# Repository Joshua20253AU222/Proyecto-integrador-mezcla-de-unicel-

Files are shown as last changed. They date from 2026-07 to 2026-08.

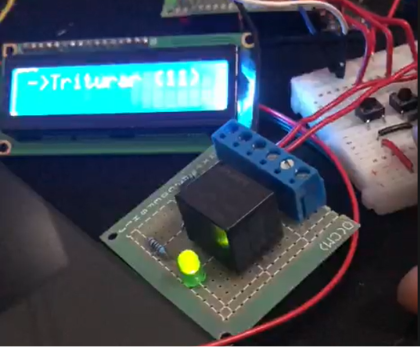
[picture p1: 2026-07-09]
Imágenes/Relevador prueba.png

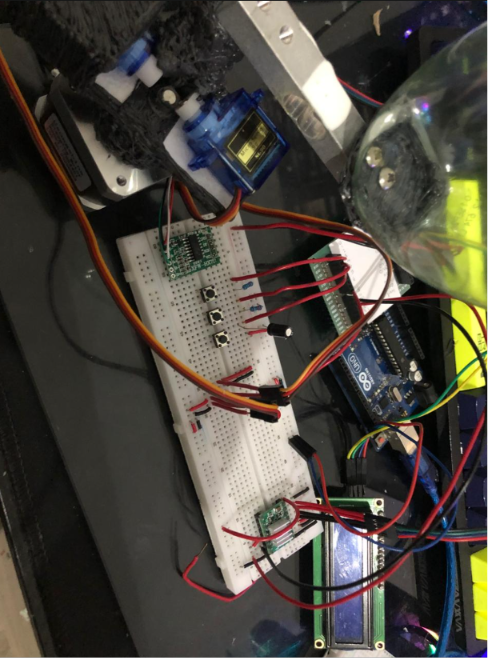
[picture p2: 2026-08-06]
Imágenes/Circuito de control del brazo recolector.png

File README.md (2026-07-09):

# Proyecto-integrador-mezcla-de-unicel-
Nombre del proyecyo:
<h3>Diseño y desarrollo de sistema semi automático de mezcla para la elaboración de bloques ecológicos de cemento y unicel.</h3>

El proyecto se enfoca en hacer una mezcla basada principalmente en unicel para la elaboración de placas o blocks con unicel, haciendo que estas sean ligeras y termoasilantes. Su uso varía desde aplicaciones en fachadas para disminución de temperaturas en inmuebles a una opción de mezcla para uso decorativo, como pisos para jardineras, etc.

El proyecto se divide en 3 sistemas clave:

<ol>
<li type="circle">Sistema de triturado:</li>
<i>Se encarga de triturar el unicel y alamacenarlo en una tolva para su posterior uso.</i>
<br><br>
<li type="circle">Sistema de mesurado:</li>
<i>Se encarga de cuantificar y dosificar los materiales necesarios para hacer la mezcla.</i>
<br><br>
<li type="circle">Sistema de Mezclado:</li>
<i>Se encarga de mezclar los materiales para obtener la mezcla final.</i>

</ol>

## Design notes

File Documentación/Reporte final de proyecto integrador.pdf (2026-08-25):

## UNIVERSIDAD TECNOLÓGICA EMILIANO ZAPATA DEL ESTADO DE

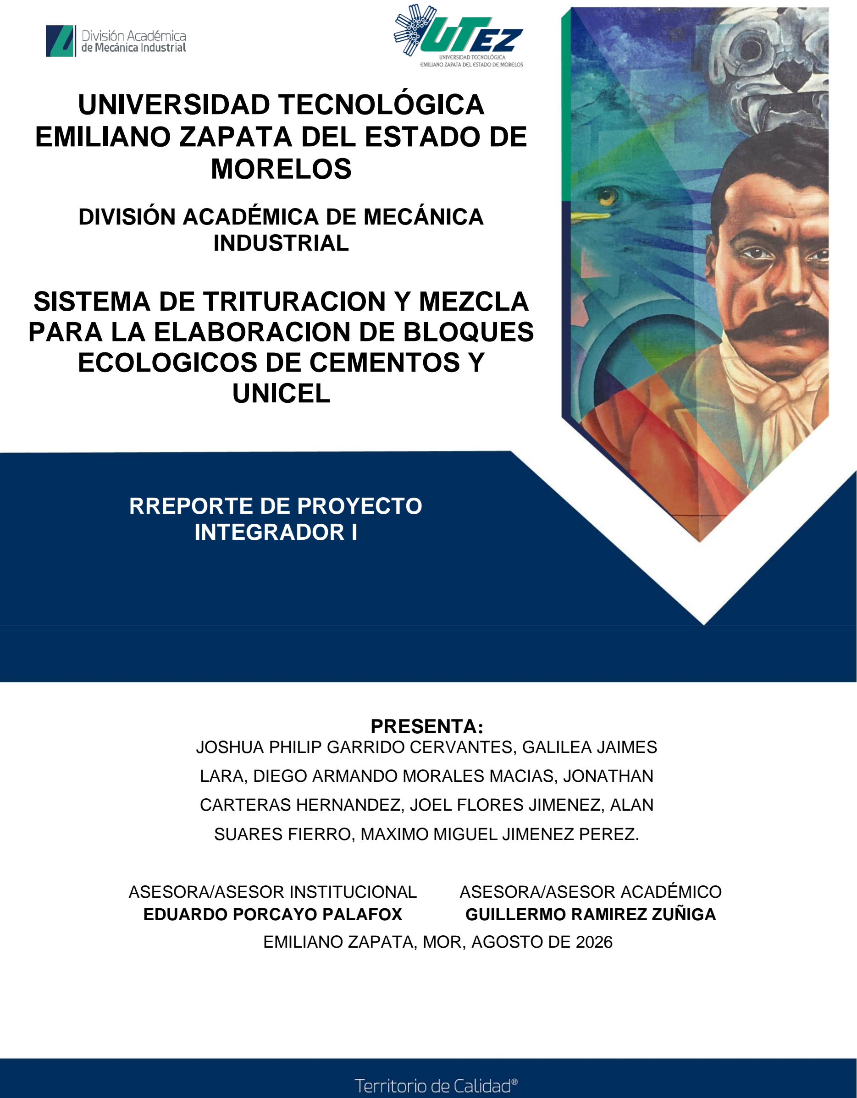
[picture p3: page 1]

PRESENTA:
JOSHUA PHILIP GARRIDO CERVANTES, GALILEA JAIMES

LARA, DIEGO ARMANDO MORALES MACIAS, JONATHAN

CARTERAS HERNANDEZ, JOEL FLORES JIMENEZ, ALAN

SUARES FIERRO, MAXIMO MIGUEL JIMENEZ PEREZ.

ASESORA/ASESOR INSTITUCIONAL | ASESORA/ASESOR ACADÉMICO
EDUARDO PORCAYO PALAFOX | GUILLERMO RAMIREZ ZUÑIGA

## RREPORTE DE PROYECTO INTEGRADOR I

EMILIANO ZAPATA, MOR, AGOSTO DE 2026

## MORELOS

## DIVISIÓN ACADÉMICA DE MECÁNICA INDUSTRIAL

## SISTEMA DE TRITURACION Y MEZCLA PARA LA ELABORACION DE BLOQUES ECOLOGICOS DE CEMENTOS Y UNICEL

## CONTENIDO

Índice de figuras

Índice de tablas

Agradecimientos

Resumen

Summary

REFERENCIAS

## ÍNDICE DE FIGURAS

Figura 5.1 Bosquejos finales del ensamblado total de la mezcladora y la trituradora 16

Figura 12.1 Estructura principal realizada con el módulo mezclador en la parte inferior

Figura 14.1 Mezcla de unicel, arena y agua para la formulación del bloque hexagonal

Figura 15.1 Bloque realizado a partir de la trituración de unicel y la mezcla con

Figura 16.1 Sistemas de almacenaje de arena para después integrarlo con el

## ÍNDICE DE TABLAS

## AGRADECIMIENTOS

Agradezco a:

- A mis profesores, por compartir sus conocimientos, guiarnos pacientemente a

lo largo de este proyecto integrador y brindarnos el apoyo técnico necesario

para llevar a cabo la construcción de este prototipo.

- A la Universidad Tecnológica Emiliano Zapata del Estado de Morelos (UTEZ),

por facilitarnos las instalaciones, laboratorios y herramientas indispensables

para el desarrollo, manufactura y pruebas de este sistema.

- A mis compañeros de equipo, por su dedicación, esfuerzo compartido y trabajo

constante durante las doce semanas de desarrollo para hacer realidad este

proyecto.

## RESUMEN

En la actualidad, las instituciones de educación superior enfrentan el reto de

implementar soluciones tecnológicas que respondan de manera efectiva a los

problemas de contaminación y gestión de residuos que afectan al país. Por ello,

a través de la investigación aplicada y el desarrollo de proyectos integradores

sustentables, las universidades reafirman su responsabilidad social y ambiental,

buscando transferir tecnologías eficientes que beneficien a los sectores

comunitario, productivo.

En este documento se encuentra el desarrollo de un proyecto realizado en el

ámbito de la Universidad Tecnológica Emiliano Zapata del Estado de Morelos,

a fin de determinar la viabilidad y diseño de un sistema semiautomático de flujo

continuo para el reciclaje de poliestireno expandido (unicel). El objetivo es que

la institución cuente con una alternativa tecnológica eficiente para transformar

un residuo de alto impacto ecológico en un material constructivo termoaislante

de valor agregado.

La investigación incluye el planteamiento de la problemática derivada del uso

excesivo y la difícil degradación del unicel, así como los diferentes elementos

que describen la forma en que se diseñó el sistema y sus alcances. De esta

manera, se tiene claramente definido el objetivo a alcanzar y los medios técnicos

que se utilizarán para dicho propósito.

Todo proyecto de integración tecnológica requiere de un marco teórico base que

fundamente la investigación realizada, de tal forma que le dé la veracidad y

objetividades requeridas. Por lo cual, se exponen de forma explícita los

fundamentos de la dosificación de materiales (cemento, cal, arena y unicel), los

principios del aislamiento térmico y el ahorro energético en inmuebles.

La determinación de la aplicabilidad del sistema, objetivo principal de este

trabajo, se desarrolla de forma clara, detallando el proceso de automatización y

control a cargo del operador. A través de diferentes técnicas de diseño, se

obtiene un trabajo significativo que culmina con la creación de un manual de

operación para la fabricación de paneles y bloques ligeros, lo que da pie a una

solución de utilidad y diagnóstico para la gestión ambiental y constructiva dentro

y fuera de la universidad.

## SUMMARY

Currently, higher education institutions face the challenge of implementing

technological solutions that effectively address the pollution and waste

management problems affecting the country. Therefore, through applied

research and the development of sustainable, integrated projects, universities

reaffirm their social and environmental responsibility, seeking to transfer efficient

technologies that benefit the community and productive sectors.

This document presents the development of a project carried out at the Emiliano

Zapata Technological University in the State of Morelos, aimed at determining

the feasibility and design of a semi-automatic, continuous-flow system for

recycling expanded polystyrene (Styrofoam). The objective is for the institution

to have an efficient technological alternative for transforming a high-impact

ecological waste product into a value-added, thermally insulating building

material.

The research includes an analysis of the problems arising from the excessive

use and slow degradation of Styrofoam, as well as the various elements that

describe how the system was designed and its scope. In this way, the objective

to be achieved and the technical means to be used for this purpose are clearly

defined.

Every technological integration project requires a basic theoretical framework to

support the research conducted, thus providing the necessary veracity and

objectivity. Therefore, the fundamentals of material dosage (cement, lime, sand,

and polystyrene), the principles of thermal insulation, and energy savings in

buildings are explicitly presented.

4

The determination of the system's applicability, the main objective of this work,

is clearly developed, detailing the automation and control process managed by

the operator. Through different design techniques, significant work is obtained,

culminating in the creation of an operating manual for the manufacture of

lightweight panels and blocks. This provides a useful and diagnostic solution for

environmental and construction management both within and outside the

university.

## CAPÍTULO 1.DESCRIPCIÓN DEL PROYECTO

### 1.1 Planteamiento del problema

El unicel, por años ha sido un material difícil de manejar en el área de reciclaje.

Su uso es principalmente desechable y su huella ecológica es muy alta, debido

a que:

- No es biodegradable: tarda más de 500 años en degradarse.
- Amenaza a la fauna: Los animales marinos y aves lo confunden con

alimento.

- Genera micro plásticos: Se desmenuza fácilmente, contaminando suelas,

ríos y océanos.

En la Universidad Tecnológica Emiliano Zapata del Estado de Morelos, a pesar

de que está prohibido el ingreso y uso del unicel, por diversos factores sigue

ingresando este material a la universidad. Por lo que, buscar qué hacer con este

material puede ser un punto de interés para la universidad.

Esta mezcla, al usarse en estructuras o edificios, permite un aislamiento de

temperatura considerable. Y en caso de inmuebles que usen aires

acondicionados, implica un ahorro de energía, al contener y mantener una

temperatura agradable, evitando cargos energéticos excesivos.

### 1.2 Objetivos

### 1.2.1 General

Buscar la forma de reciclar el unicel en el plantel, al mismo tiempo de darle un

uso que no implique que el material se vuelva en otro producto desechable.

Crear un sistema que utilice el unicel para que, en conjunto de otros materiales

(como cemento, cal y/o arena), formar una mezcla de unicel y estos materiales para hacer placas/blocks termo aislantes y de peso ligero para uso interior y

exterior.

### 1.2.2 Específicos

Crear un sistema que pueda hacer la mezcla de forma semi automática de flujo

continuo, siendo que exista un operador que programe la máquina primero,

tomando en cuenta, se generan los siguientes puntos:

- Los materiales se colocan en la máquina, esta misma los dosifica.
- La mezcla no es específica, el operador es el encargado técnico de

programar el sistema para que la máquina genere la mezcla con diferentes

propiedades según las necesidades y área de aplicación.

Además, se busca generar un pequeño manual de operación, el cuál

especificará dos principales tipos de mezcla: Para paneles y para blocks.

Ambos teniendo cantidades de material diferentes, siendo esta la idea principal.

### 1.3 Justificación

Hacer este sistema da la oportunidad a empresas, centros de acopio y escuelas

medianas o grandes, de reciclar unicel de forma beneficiosa.

Así como ayudar a generar material de construcción que sea más viable de

transportar que el mismo unicel, ya que, al transportar unicel, se transporta más

aire que material (un 98% de aire aproximadamente).

De la misma forma se puede usar de forma casera este sistema, trayendo

beneficios a muchas personas y ampliando el área de oportunidad del proyecto.

En general, es una solución a los residuos excesivos del unicel en un enfoque

que beneficia al bienestar de las personas quienes usen esta tecnología en

aulas, oficinas y hogares en tanto al manejo de temperaturas.

### 1.4 Alcances

Alcances:

- Las propiedades de los materiales y su calidad son responsabilidad del

operador.

- La máquina solo manejará el uso y mesurado de 3 materiales por mezcla.
- Se harán dos principales moldes, pero la mezcla puede usarse para un

molde personalizado.

- El uso de unicel debe de pasar por un proceso de limpieza en caso de

contener residuos de alimentos o grasas.

- Se especificará en el manual una forma en la que se puedan colocar las

placas aislantes fuera de un edificio, casa o inmueble.

### 1.5 Datos generales de la empresa

Nombre

Universidad Tecnología Emiliano Zapata Del Estado De Morelos

Logotipo

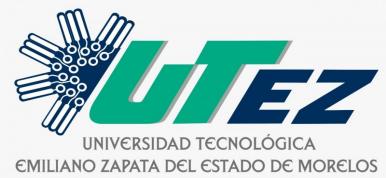
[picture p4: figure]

Figura 1.1 Logotipo de la empresa

Dirección

Avenida Universidad Tecnológica 1 Palo Escrito, 62765 Emiliano Zapata, Mor.

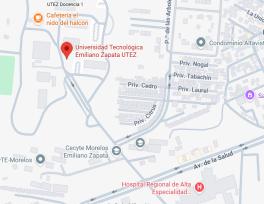
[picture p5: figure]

Figura 1.2 Ubicación de la empresa

Giro

La Universidad Tecnológica Emiliano Zapata (UTEZ) se dedica a ofrecer programas

educativos de Técnico Superior Universitario (TSU), Licenciatura e Ingeniería. La

universidad forma profesionales con profundos niveles tecnológicos que responden a

los requerimientos productivos y sociales de la región y del país.

## CAPÍTULO 2.MARCO TEÓRICO

### 2.1 Revisión Bibliográfica

El poliestireno expandido (EPS) es un polímero caracterizado por una estructura

celular constituida en un 98% por aire, lo que le otorga una densidad

extremadamente baja y dificulta su gestión como residuo sólido. De acuerdo con Veit

y Bernardes (2014), el procesamiento mecánico mediante trituración in situ

representa la etapa técnica fundamental para romper la estructura del material,

reduciendo su volumen físico y permitiendo su almacenamiento y transporte

eficiente.

En el ámbito de los materiales sostenibles, Kan y Demirboğa (2009) demostraron que

la reincorporación de granulado de EPS como sustituto parcial de los agregados

pétreos en mezclas permite elaborar concreto ligero. Este compuesto reduce el peso

propio de los elementos constructivos y conserva propiedades mecánicas adecuadas

para aplicaciones no estructurales. Asimismo, la literatura sobre prefabricados de

concreto señala que la geometría hexagonal en adoquines y bloques modulares

optimiza la distribución de cargas laterales, mejorando el ensamblaje y la estabilidad

en estructuras de retención como jardineras y banquetas (Pérez y Gómez, 2018). Por

este motivo, el estudio de estas tecnologías permite fundamentar el diseño de la

trituradora mecánica y la fabricación de bloques hexagonales ecológicos para el

campus UTEZ (Martínez y López, 2022).

## CAPÍTULO 3.DESARROLLO

### 3.1 Planeación

La ejecución del proyecto se estructuró de manera secuencial mediante un plan de

trabajo basado en entregables semanales para garantizar el avance constante en el

diseño, manufactura y ensamblaje del sistema. A continuación, se detallan las fases

desarrolladas:

Fase 1: Concepción y Bosquejos Iniciales

Se elaboraron los primeros bocetos y esquemas a mano alzada para definir la

distribución espacial, el principio de triturado y la integración mecánica entre la

trituradora y la mezcladora.

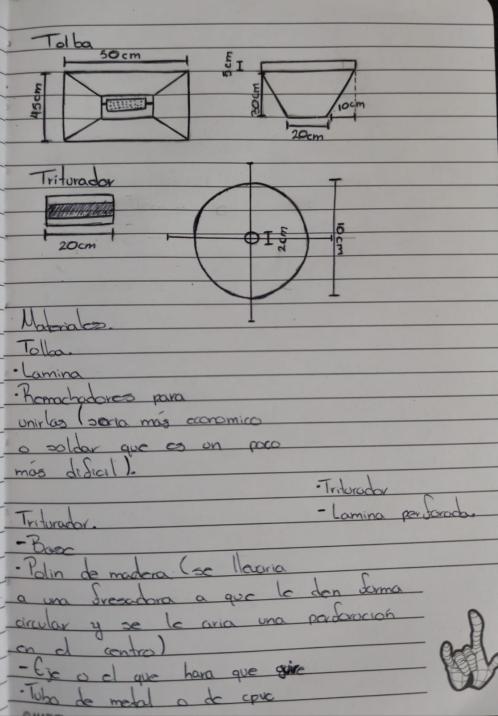
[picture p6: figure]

Figura 3.1 Bosquejos realizados para la tolva.

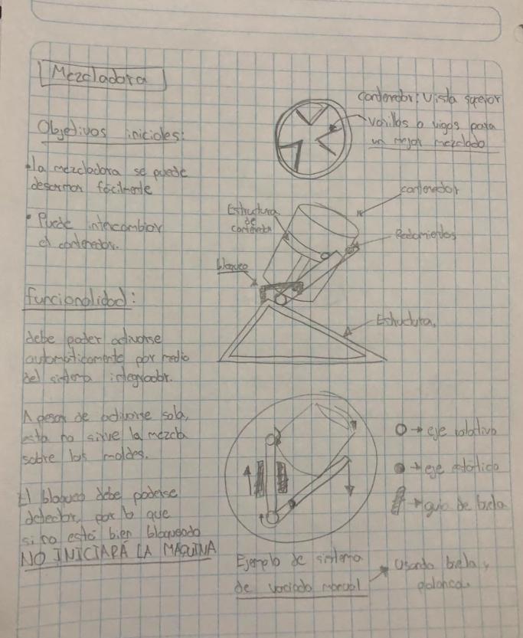
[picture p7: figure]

Figura 4.1 Bosquejos para la realización de la mezcladora

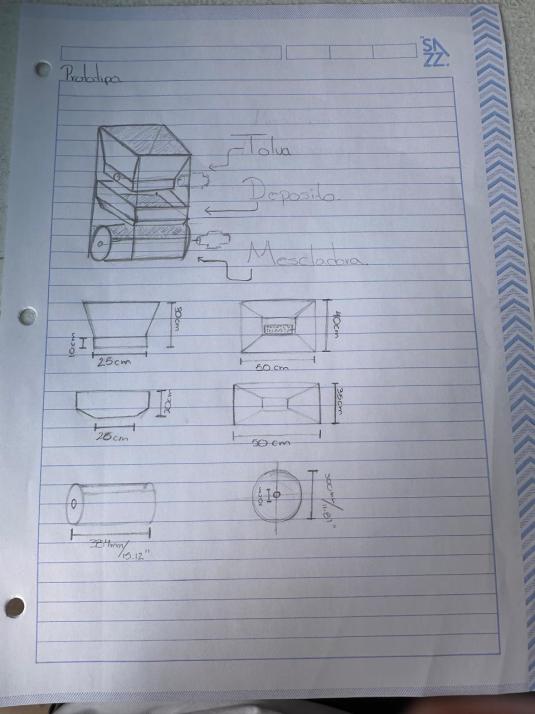
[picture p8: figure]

Figura 5.1 Bosquejos finales del ensamblado total de la mezcladora y la trituradora
Figura 3.3 Bosquejos finales del ensamblado total de la mezcladora y la trituradora.

Fase 2: Diseño Electrónico y Sistema de Control

Se diseñó el circuito de control electrónico para la activación, inversión de giro y

protección de los motores eléctricos de la trituradora y de la mezcladora, asegurando

un arranque seguro y eficiente.

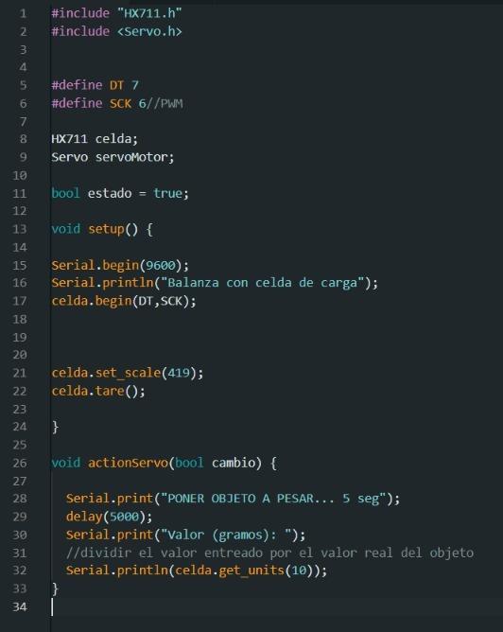
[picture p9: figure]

Figura 6.1 Código para los sistemas de control

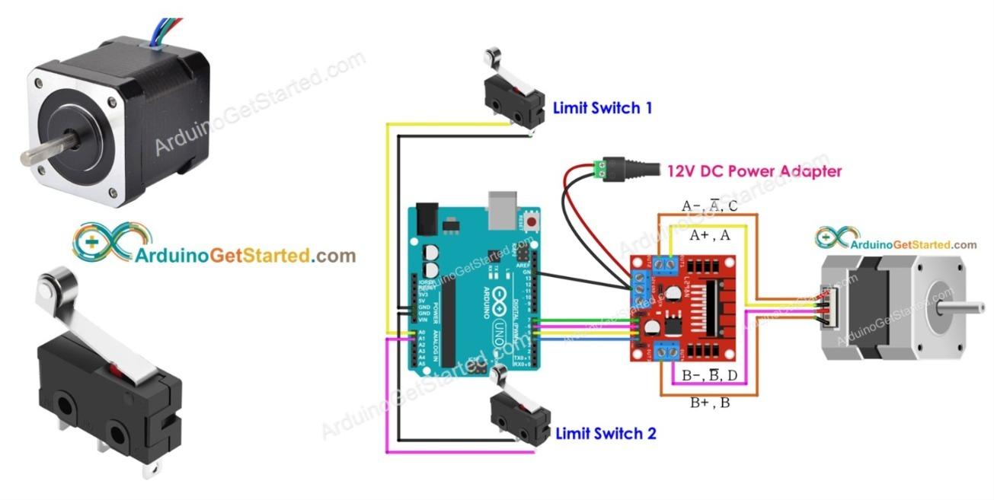
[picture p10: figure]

Figura 7.1 Diagrama de los sistemas de control

Fase 3: Modelado Mecánico en SolidWorks (CAD)

Se realizó el diseño tridimensional detallado de la estructura completa en SolidWorks,

incluyendo el ensamble de las cuchillas, flechas, soportes, chasis principal,

mezcladora y la tolva de alimentación.

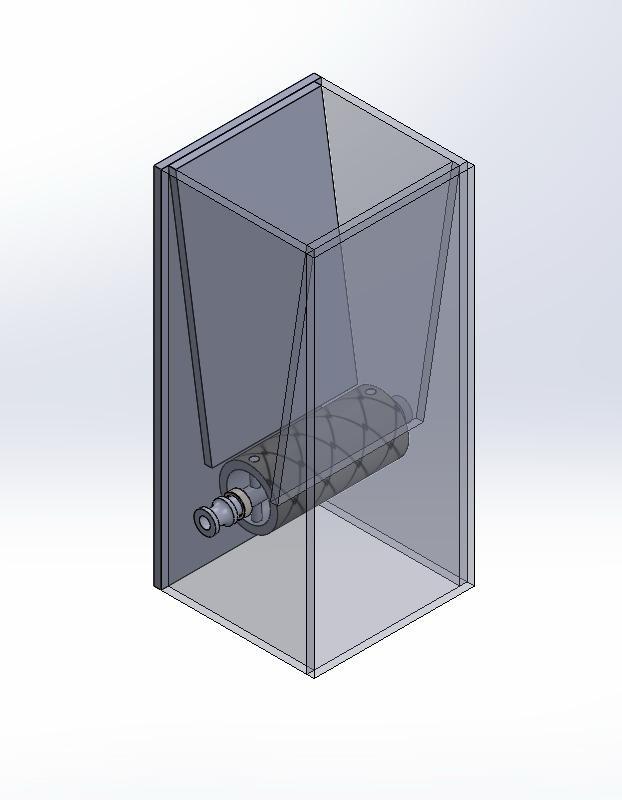
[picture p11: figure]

Figura 8.1 Prototipo de ensamble en solidworks

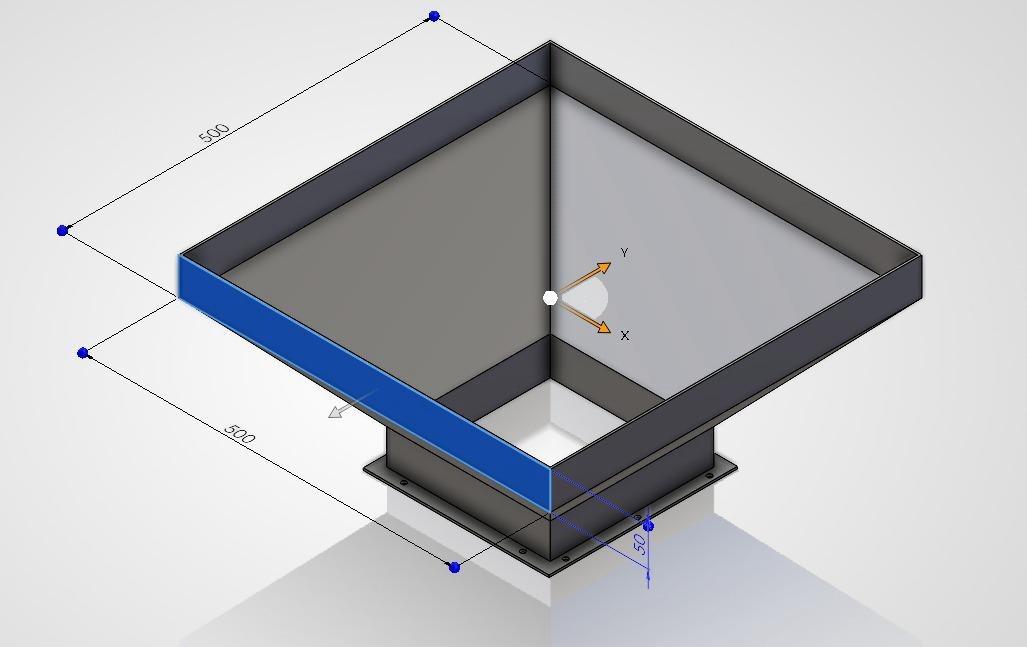
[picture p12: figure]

Figura 9.1 Diseño de la tolva realizado en solidworks

Fase 4: Adquisición de Materiales y Trazado

Se seleccionaron y adquirieron los insumos mecánicos, destacando la compra de

lámina metálica para la tolva, perfiles estructurales, motores y componentes para el

motor.

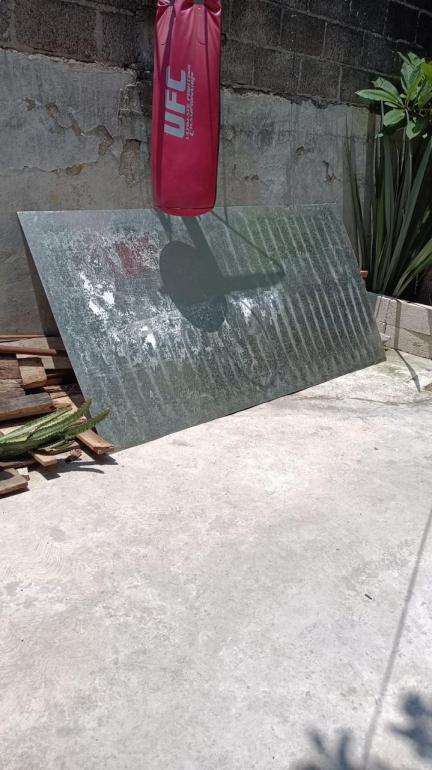
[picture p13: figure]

Figura 10.1 Adquisición de lámina para la realización de la tolva

Fase 5: Manufactura y Armado de la Tolva y Estructura

Se realizaron los trazos, cortes de lámina, dobles y soldadura para la fabricación de la

tolva de alimentación, así como el armado de la base estructural que soporta tanto el

módulo de triturado como la mezcladora.

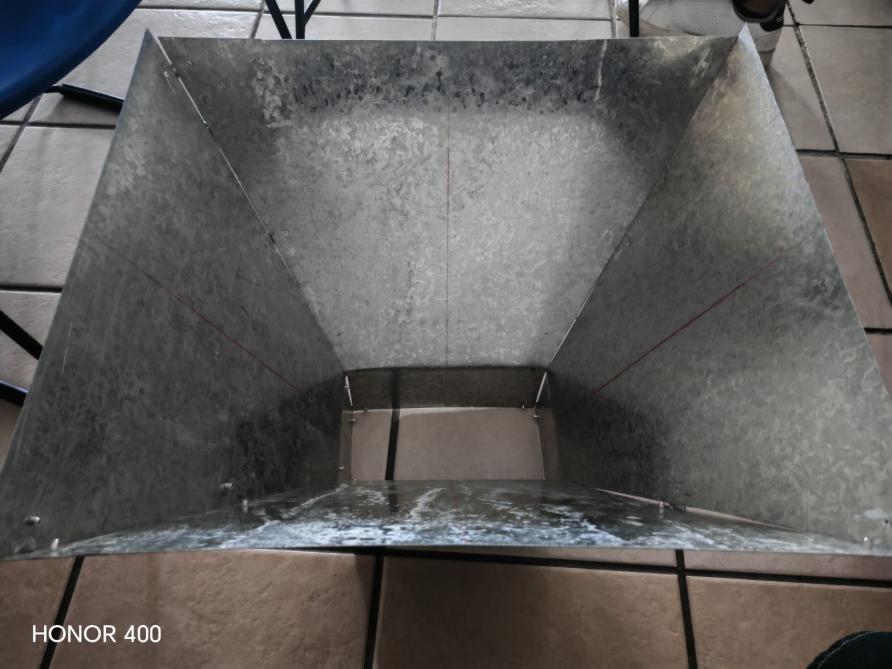
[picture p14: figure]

Figura 11.1 Ensamblado de la tolva hecha en lamina

Fase 6: Integración, Pruebas y Seguimiento Semanal

Bajo un esquema de revisión constante, se presentaron avances semanales de

progreso. Se concluyó con el ensamblaje general de los sistemas mecánico y eléctrico

para realizar las pruebas iniciales de triturado de unicel y mezclado de concreto ligero.

Tabla 1.1 Diagrama de Gantt, esquema de revisión constante.
| Nombre del proyecto: Sistema de trituración y mezcla para la elaboración de bloques ecológicos de cemento y unicel. Periodo: del 3 de Mayo del 2026 al 24 de Agosto del 2026.
Fase / Actividad | S1 | S2 | S3 | S4 | S5 | S6 | S7 | S8 | S9 | S10 | S11 | S12
bosquejos y concepción del diseño | ✓ | ✓
Diseño electrónico (control de motores) | | ✓ | ✓
Modelado 3D en SolidWorks | | | ✓ | ✓ | ✓
Adquisición de lámina y materiales | | | | | ✓ | ✓
Corte, trazo y habilitado de tolva | | | | | | ✓ | ✓
Ensamble de tolva y chasis principal | | | | | | | ✓ | ✓
Integración mecánica y eléctrica | | | | | | | | | ✓ | ✓
Pruebas de triturado y mezcla | | | | | | | | | | ✓ | ✓
Reportes semanales y ajustes finales | ✓ | ✓ | ✓ | ✓ | ✓ | ✓ | ✓ | ✓ | ✓ | ✓ | ✓ | ✓

### 3.2 Desarrollo del proyecto

La ejecución del proyecto consistió en la construcción y ensamble de una trituradora

de unicel con su módulo de mezclado, desarrollando desde la parte mecánica hasta la

electrónica de control. El proceso se llevó a cabo por etapas, iniciando con la

fabricación de las piezas de lámina, el armado del bastidor de soporte, la conexión de los circuitos eléctricos para los motores y la realización de las pruebas de

funcionamiento con el material reciclado.

Habilitado y Manufactura de la Tolva de Alimentación

Trazado y Corte Métrico: A partir de los planos tridimensionales generados en el

software CAD (SolidWorks), se trasladaron las dimensiones reales a láminas metálicas

galvanizadas. Se realizaron cortes trapezoidales de alta precisión para conformar las

cuatro caras convergentes de la tolva.

Conformado Mecánico y Ensamble: Las piezas de lámina cortadas se sometieron a

procesos de dobles, alineación y ensamble mecánico mediante remaches y soldadura.

La geometría obtenida corresponde a una pirámide trunca convergente, diseñada

específicamente para aprovechar la fuerza de gravedad y guiar eficientemente los

residuos de poliestireno expandido (EPS) hacia el mecanismo de corte superior.

Fabricación de la Estructura Principal y Módulo Mezclador

Bastidor Estructural: Se fabricó y soldó un chasis tubular rígido de acero para brindar

estabilidad mecánica y absorber las vibraciones generadas por los motores eléctricos

durante el proceso de triturado y mezclado.

Integración del Sistema Mezclador: En la sección inferior del bastidor se adaptó e

instaló un contenedor cilíndrico equipado con paletas internas de mezclado dispuestas

de forma radial. Este diseño asegura una turbulencia adecuada para homogeneizar el

unicel granulado con el cemento, agua y arena.

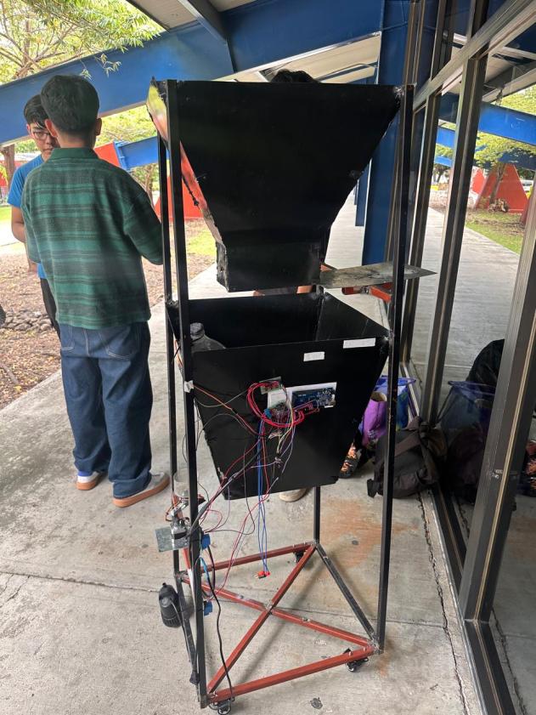
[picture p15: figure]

Figura 12.1 Estructura principal realizada con el módulo mezclador en la parte inferior

Automatización, Electrónica de Control e Interfaz de Usuario

Unidad de Control Embebido: Se diseñó e implementó un sistema basado en un

microcontrolador (placa de desarrollo) para gestionar la activación, temporización y

secuencia de operación de los motores eléctricos de triturado y mezclado.

Interfaz de usuario: Se integró una pantalla de cristal líquido (LCD 16 x 2) en el panel

frontal de la tolva, junto con botones de navegación. Esto permite al usuario interactuar

con un menú dinámico (MENU PRINCIPAL > Mezclar) para seleccionar y monitorear

los ciclos de trabajo en tiempo real.

Módulos de Potencia y Dosificación: Se diseñaron e interconectaron placas de

circuito impreso (PCB) dedicadas al control de potencia, drivers de motores y

regulación de voltaje. Adicionalmente, se incorporaron servomotores y motores a

pasos para el control de compuertas y la dosificación automatizada de insumos.

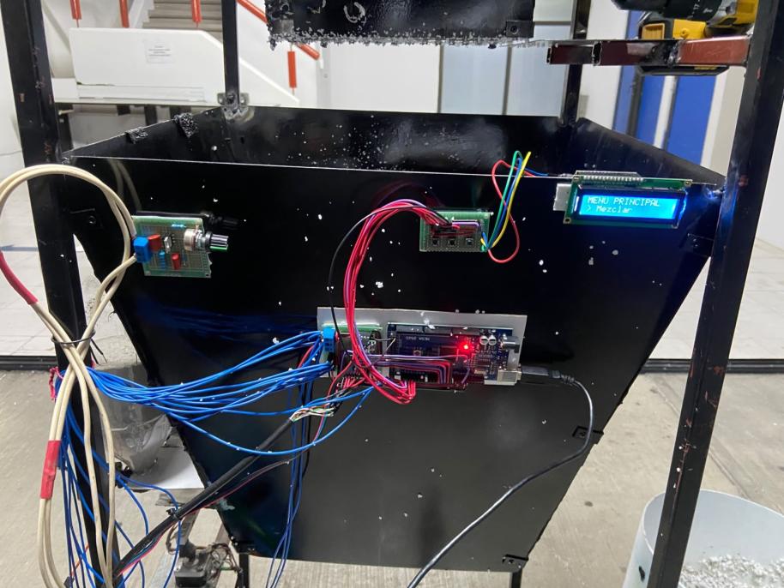
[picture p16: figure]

Figura 13.1 Integración de módulos de potencia y dosificación.

Pruebas de Funcionamiento, Triturado y Colado de Bloques Hexagonales

Reducción Volumétrica: Tras la integración mecatrónica completa, se realizaron

pruebas operativas utilizando unicel recolectado en las distintas áreas del campus

(cafetería y laboratorios), logrando romper las bolsas de aire del EPS y reduciendo su

volumen entre un 70% y un 90%.

Obtención de Concreto Ligero: El granulado resultante se transfirió directamente al

módulo mezclador para formular la dosificación de concreto ligero.

Fabricación de Elementos Modulares: La mezcla maleable obtenida se vertió en

moldes con geometría hexagonal para fabricar bloques ecológicos entrelazables,

destinados a la edificación de jardineras sustentables dentro del campus de la UTEZ.

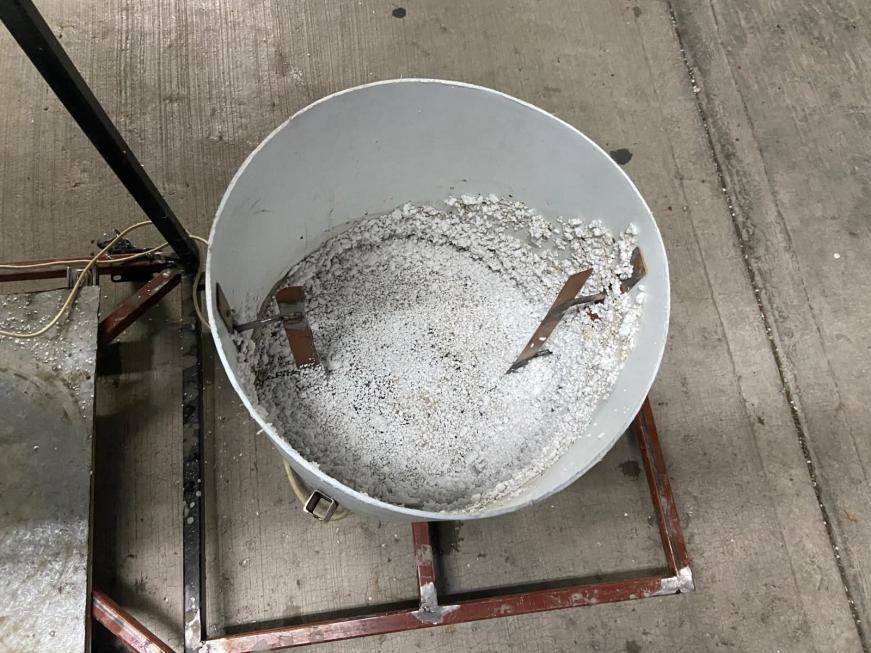
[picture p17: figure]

Figura 14.1 Mezcla de unicel, arena y agua para la formulación del bloque hexagonal

### 3.2.1 Ejecución del Proyecto

La ejecución del proyecto consistió en la construcción y ensamble de una trituradora

de unicel con su módulo de mezclado, desarrollando desde la parte mecánica hasta la

electrónica de control. El proceso se llevó a cabo por etapas, iniciando con la

fabricación de las piezas de lámina, el armado del bastidor de soporte, la conexión de

los circuitos eléctricos para los motores y la realización de las pruebas de

funcionamiento con el material reciclado.

Habilitado y Manufactura de la Tolva de Alimentación

Trazado y Corte Métrico: A partir de los planos tridimensionales generados en el

software CAD (SolidWorks), se trasladaron las dimensiones reales a láminas metálicas

galvanizadas. Se realizaron cortes trapezoidales de alta precisión para conformar las

cuatro caras convergentes de la tolva.

Conformado Mecánico y Ensamble: Las piezas de lámina cortadas se sometieron a

procesos de doblez, alineación y ensamble mecánico mediante remaches y soldadura.

La geometría obtenida corresponde a una pirámide trunca convergente, diseñada para

guiar los residuos de poliestireno expandido (EPS) hacia el mecanismo de corte.

Fabricación de la Estructura Principal y Módulo Mezclador

Bastidor Estructural: Se fabricó y soldó un chasis tubular rígido de acero para brindar

estabilidad mecánica y absorber las vibraciones generadas por los motores eléctricos

durante el proceso de triturado y mezclado.

Integración del Sistema Mezclador: En la sección inferior del bastidor se adaptó e

instaló un contenedor cilíndrico equipado con paletas internas de mezclado dispuestas

de forma radial. Este diseño asegura una turbulencia adecuada para homogeneizar el

unicel granulado con el cemento, agua y arena.

Automatización, Electrónica de Control e Interfaz de Usuario

Unidad de Control Embebido: Se diseñó e implementó un sistema basado en un

microcontrolador para gestionar la activación, temporización y secuencia de operación

de los motores eléctricos de triturado y mezclado.

Interfaz de usuario: Se integró una pantalla de cristal líquido (LCD 16 x 2) en el panel

frontal, junto con botones de navegación. Esto permite al usuario interactuar con un

menú dinámico (MENU PRINCIPAL > Mezclar) para seleccionar y monitorear los ciclos

de trabajo en tiempo real.

Módulos de Potencia y Dosificación: Se diseñaron e interconectaron placas de

circuito impreso (PCB) dedicadas al control de potencia, drivers de motores y

regulación de voltaje. Adicionalmente, se incorporaron servomotores y motores a

pasos para el control de compuertas y la dosificación de insumos.

Pruebas de Funcionamiento, Triturado y Colado de Bloques Hexagonales

Volumétrica: Tras la integración mecatrónica completa, se realizaron pruebas

operativas utilizando unicel recolectado en el campus, logrando romper la estructura

del EPS y reduciendo su volumen.

Obtención de Concreto Ligero: El granulado resultante se transfirió al módulo

mezclador para formular la dosificación de concreto ligero.

Fabricación de Elementos Modulares: La mezcla obtenida se vertió en moldes con

geometría hexagonal para fabricar bloques ecológicos entrelazables, destinados a la

edificación de jardineras en el campus.

### 3.3 Entrega del proyecto

La entrega final del proyecto se realizó mediante una evaluación presencial en la que

participaron el profesor encargado de la asignatura y un docente evaluador invitado.

El evento se estructuró en dos etapas principales: una exposición teórica y una

demostración técnica en vivo.

Presentación Teórico-Metodológica Se expuso ante los docentes una presentación

ejecutiva estructurada con los aspectos clave de la investigación y desarrollo:

Planteamiento del Problema: Exposición sobre la problemática ambiental generada

por el poliestireno expandido (EPS) dentro del campus y la necesidad de reducir su

impacto volumétrico.

Justificación y Objetivos: Justificación del proyecto enfocado en la sustentabilidad y

presentación de los objetivos generales y específicos para la automatización del

proceso de reciclaje.

Resultados Esperados: Explicación del alcance técnico, el diseño en CAD

(SolidWorks), la arquitectura de control implementada y el aprovechamiento del

granulado para la economía circular.

Muestra de Producto Terminado y Demostración Operativa

Exhibición de Bloques Ecológicos: Se presentaron físicamente dos bloques de

muestra elaborados previamente con la mezcla de concreto ligero y unicel triturado,

demostrando la viabilidad del material para la construcción de jardineras.

Explicación del Funcionamiento: Concluida la presentación, se realizó la explicación

técnica directamente sobre el prototipo. Se detalló el funcionamiento de la tolva de alimentación, el chasis principal, el módulo mezclador, la etapa de potencia y la interfaz

de usuario con la pantalla LCD.

Retroalimentación y Veredicto Evaluativo Tras revisar la exposición, examinar los

bloques de concreto ligero y comprobar la operación de la trituradora, el profesor

evaluador emitió su veredicto. Asimismo, los docentes destacaron el valor innovador

del sistema y concluyeron que el prototipo constituye una base sólida que podrá ser

escalada y perfeccionada en etapas futuras para optimizar el rendimiento y la

capacidad de procesamiento dentro del campus o por fuera.

## CAPÍTULO 4. RESULTADOS Y CONCLUSIONES

### 4.1 Resultados

Con la conclusión de las etapas de diseño, manufactura e integración del prototipo, se

alcanzaron satisfactoriamente los objetivos planteados al inicio del proyecto. A

continuación se presentan los resultados más relevantes obtenidos:

- Manufactura y Ensamble del Prototipo Funcional: Se construyó de manera

exitosa la estructura metálica principal junto con la tolva de alimentación en

lámina galvanizada y el recipiente cilíndrico de mezclado, logrando un

ensamblaje robusto y mecánicamente estable.

- Implementación de la Electrónica de Control y Automatización: Se integró

correctamente el sistema electrónico embebido para la gestión de los motores,

logrando la puesta en marcha de la interfaz HMI a través de la pantalla LCD y

el menú interactivo para la activación y control de los ciclos de mezclado.

- Reducción Volumétrica del Poliestireno Expandido (EPS): Durante las

pruebas de procesamiento, la trituradora demostró una capacidad efectiva para

procesar residuos de unicel recolectados en el campus, reduciendo

significativamente su volumen físico y transformándolo en un material granulado

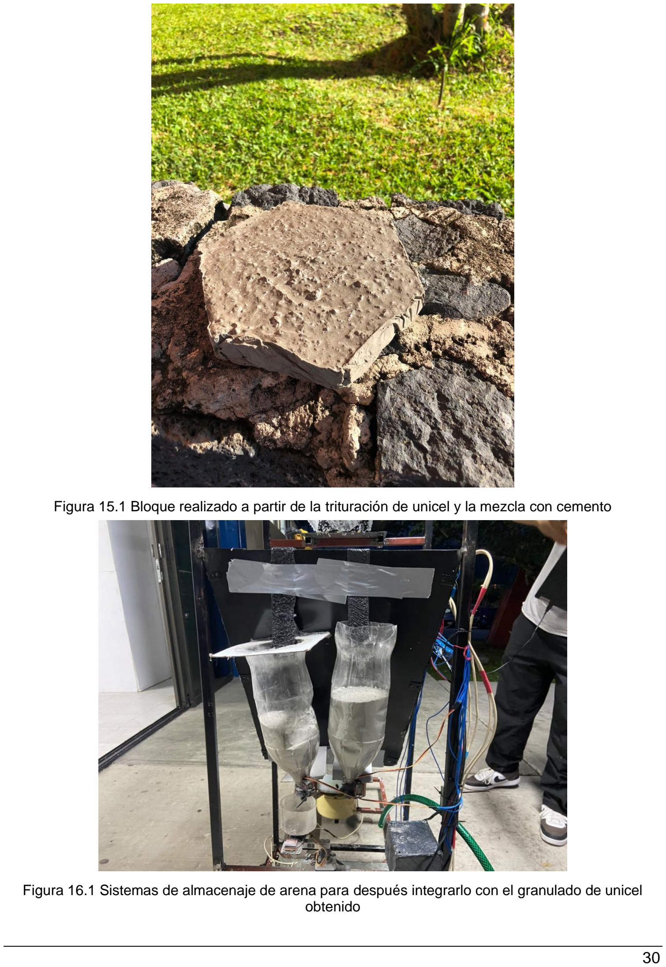
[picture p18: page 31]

Figura 15.1 Bloque realizado a partir de la trituración de unicel y la mezcla con cemento

Figura 16.1 Sistemas de almacenaje de arena para después integrarlo con el granulado de unicel obtenido

### 4.2 Conclusiones y Recomendaciones

El desarrollo del proyecto permitió la integración exitosa de sistemas mecánicos,

eléctricos y de automatización para resolver el problema de la acumulación de

poliestireno expandido (EPS) dentro de la universidad. Se lograron de manera

concreta los siguientes puntos:

- Cumplimiento de Objetivos Técnicos: Se diseñó e integró un prototipo

funcional que abarca desde la recolección del material en la tolva de

alimentación hasta el triturado y el posterior mezclado de concreto ligero.

- Reducción Volumétrica y Reciclaje: Se validó la capacidad de la máquina

para romper la estructura celular del unicel, disminuyendo sustancialmente su

volumen y transformándolo en un agregado eficiente para la fabricación de

bloques hexagonales.

- Aporte a la Economía Circular: Se demostró la viabilidad de reutilizar un

residuo de difícil degradación en la edificación de infraestructura universitaria

sustentable, promoviendo la cultura del reciclaje en el campus.

Recomendaciones

Con base en las observaciones recopiladas durante la etapa de pruebas y la

evaluación final por parte de los docentes, se sugiere contemplar las siguientes

mejoras para futuras etapas de desarrollo:

Optimización Mecánica del Sistema de Corte: Aumentar el par motor (torque) o

rediseñar la geometría de las cuchillas para optimizar el tiempo de procesamiento y

permitir el triturado de piezas de mayor densidad o volumen.

Implementación de Sensores Adicionales: Incorporar sensores de nivel en la tolva

de alimentación y en el contenedor de mezclado para automatizar por completo el paro

y arranque de los motores según el volumen detectado.

Reforzamiento del Módulo Mezclador: Reemplazar o reforzar las paletas internas

con un material de mayor calibre para asegurar un manejo óptimo de mezclas de

concreto de mayor volumen.

## REFERENCIAS

García, J. A., & Morales, F. R. (2020). Procesamiento mecánico y reciclaje de

materiales poliméricos para la construcción. Editorial Trillas.

Hernández, M. E., & Ramírez, C. L. (2021). Propiedades mecánicas del concreto ligero

adicionado con poliestireno expandido reciclado. Revista Iberoamericana de

Materiales y Edificación, 15(2), 45–58.

Martínez, J., & López, A. (2022). Aprovechamiento de polímeros reciclados en la

elaboración de elementos constructivos. Editorial Trillas.

Pérez, R., & Gómez, M. (2018). Diseño de elementos modulares prefabricados para

uso urbano. Editorial Limusa.

Sánchez, P. K., & Torres, D. M. (2019). Análisis de reducción volumétrica e impacto

ambiental en el acopio de poliestireno expandido. Revista Centroamericana de

Ingeniería y Desarrollo, 8(1), 112–124.

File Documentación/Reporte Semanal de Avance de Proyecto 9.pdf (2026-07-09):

### Universidad Tecnológica Emiliano Zapata del Estado de Morelos (UTEZ)

### Técnico Superior Universitario en Automatización

Asignatura: Proyecto Integrador I

## Datos Generales

Campo | Información
Nombre del Proyecto | Diseño y desarrollo de sistema semi automático de mezcla para la elaboración de placas de cemento y unicel.
Nombre del Equipo | Los Ecolovers
Semana No. | 8
Fecha de entrega | 25 de junio de 2026
Empresa / Institución | Universidad Tecnológica Emiliano Zapata del Estado de Morelos
Profesor | Guillermo Ramírez Zuñiga
Líder del equipo | Joshua Philip Garrido Cervantes

## Integrantes y Participación

Integrante | Rol | Actividades realizadas esta semana | % Participación
Joshua Philip Garrido Cervantes | Líder del proyecto | Bosquejos de la mezcladora | 15
Diego Armando Morales Macias | Responsable de documentación | Realización del reporte semanal | 14
Alan Suarez Fierro | Responsable de programación y calidad | Realización del primer prototipo | 15
Galilea Jaimes Lara | Responsable de sustentabilidad e impacto social | Apoyo con la información en la elaboración del reporte semanal | 14
Joel Flores Jiménez | Responsable IoT y comunicaciones | Bosquejos y detalles de la mezcladora | 14
Máximo Miguel Jiménez Pérez | Responsable de electrónica | Apoyo en la realización de primer prototipo de la trituradora | 14
Jonathan Geovanni Carteras Hernández | Responsable mecánico/diseño | Apoyo en la cotización del material | 14

# 1. Objetivo de la Semana

Describir brevemente qué se pretendía lograr durante esta semana.

- Plasmar el primer diseño de la mezcladora definiendo sus partes, funcionalidad y materiales.
- Crear el primer modelo de la trituradora funcional
- Poner en práctica el uso de un motor a pasos con el sistema integrador.

# 2. Actividades Programadas

Actividad | Responsable | Fecha programada | Estado (%)
Diseño de sistema integrador | Máximo Miguel Jiménez Pérez | Lunes 21 de Julio | 100
Obtención de material de práctica | Joshua Philip Garrido Cervantes | Martes 23 de Julio | 100
Implementación física del prototipo del sistema | Alan Suárez Fierro | Miércoles 24 de Julio | 90
Diseño de tolva | Jonathan Geovanni Carteras Hernández | Martes 23 de Julio | 100
Diseño de escala y medidas de trituradora | Joel Flores Jiménez | Miércoles 24 de Julio | 100

# 3. Actividades Realizadas

Durante esta semana se hizo la compra de ciertos materiales para poder realizar el proyecto, así también se realizó un prototipo de la pieza trituradora conectada al motor, la cual funcionaria para triturar el unicel.
También se realizaron distintos bosquejos sobre la mezcladora que se piensa realizar.

# 4. Avances Técnicos

## Hardware

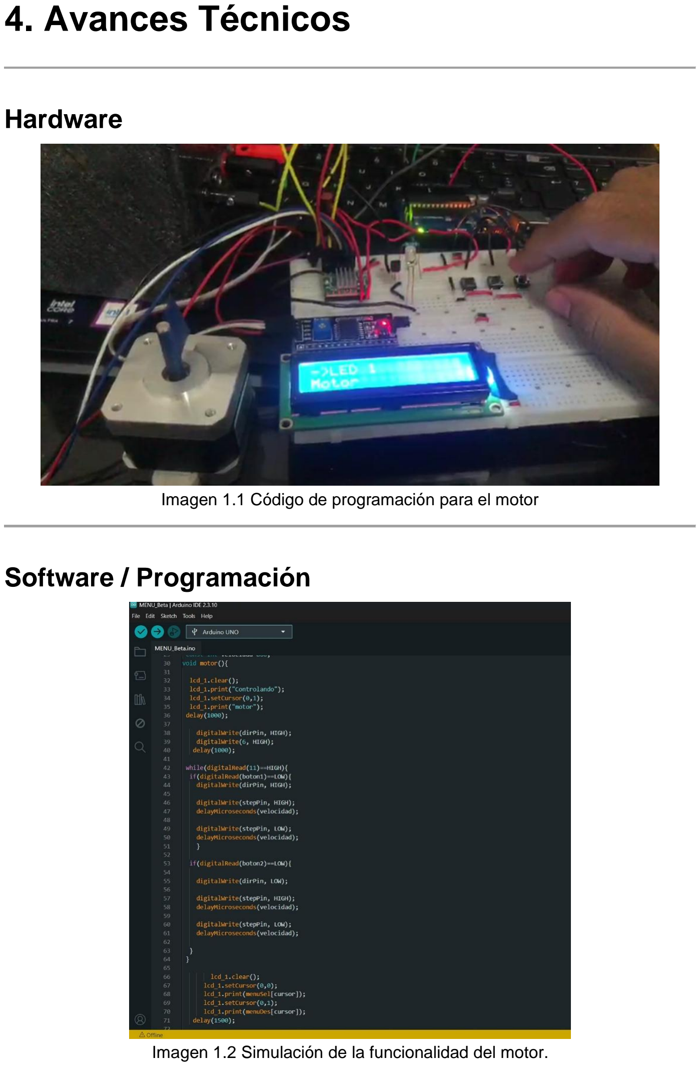
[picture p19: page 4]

Imagen 1.1 Código de programación para el motor

## Software / Programación

Imagen 1.2 Simulación de la funcionalidad del motor.

## Diseño Mecánico

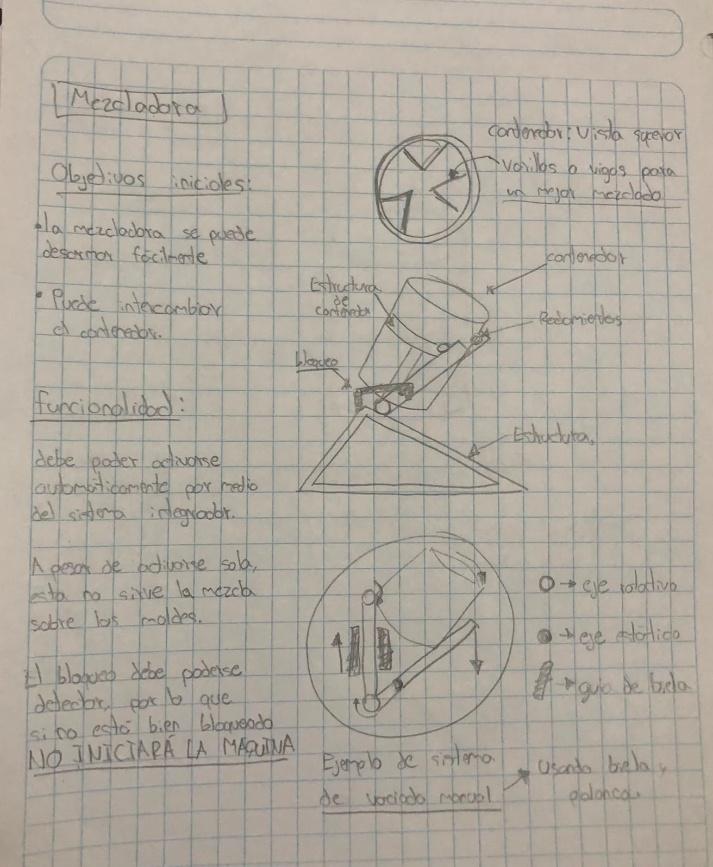
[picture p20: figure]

Imagen 1.3 Bosquejo inicial de la mezcladora

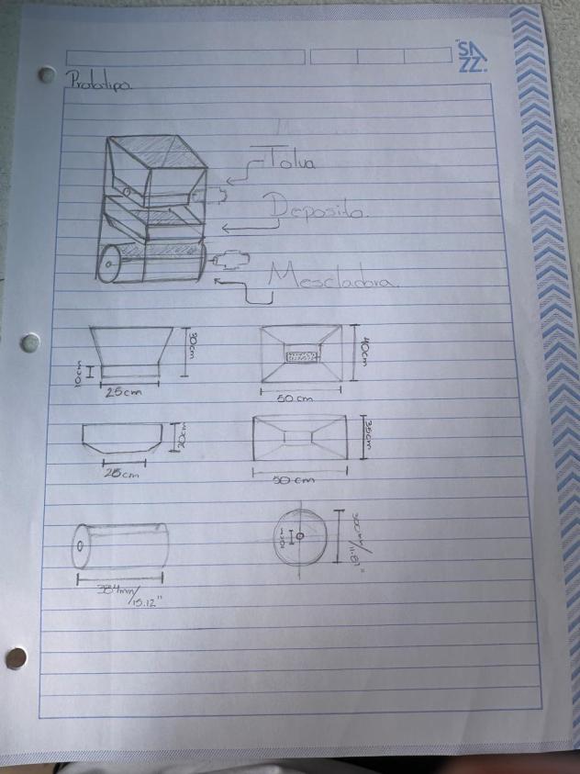
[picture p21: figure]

Imagen 1.4 Bosquejo de la mezcladora

# 5. Evidencias del Avance

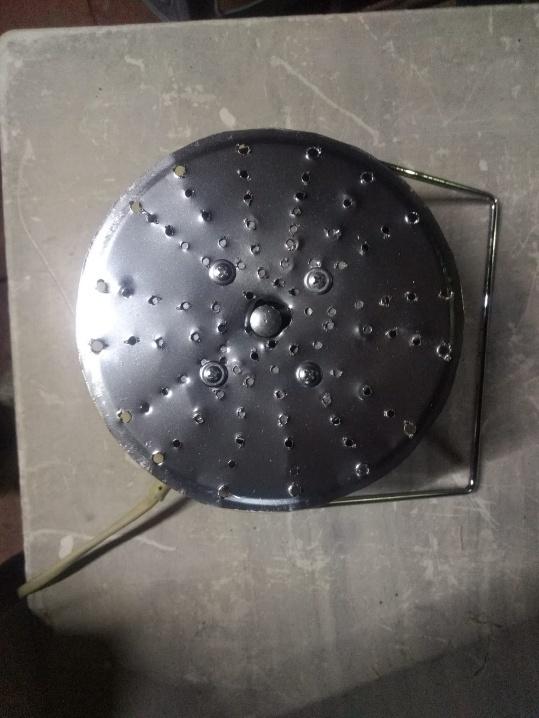
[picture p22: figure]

Imagen 1.5 vista alzada de la trituradora

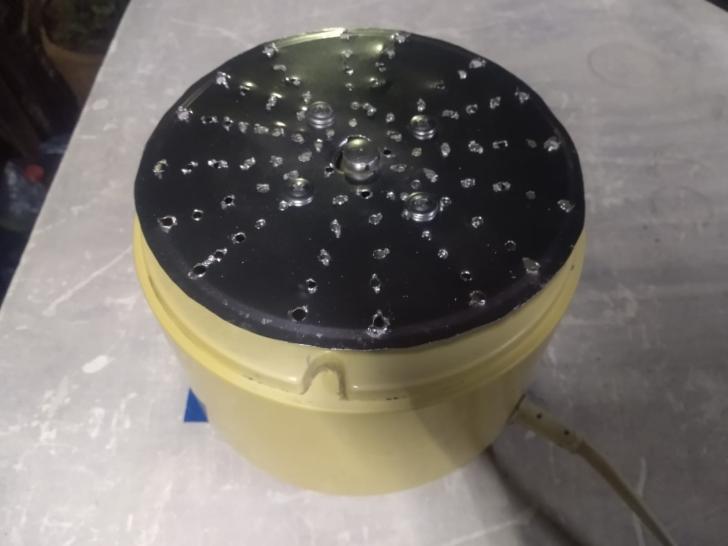
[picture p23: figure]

Imagen 1.6 Vista frontal de la trituradora

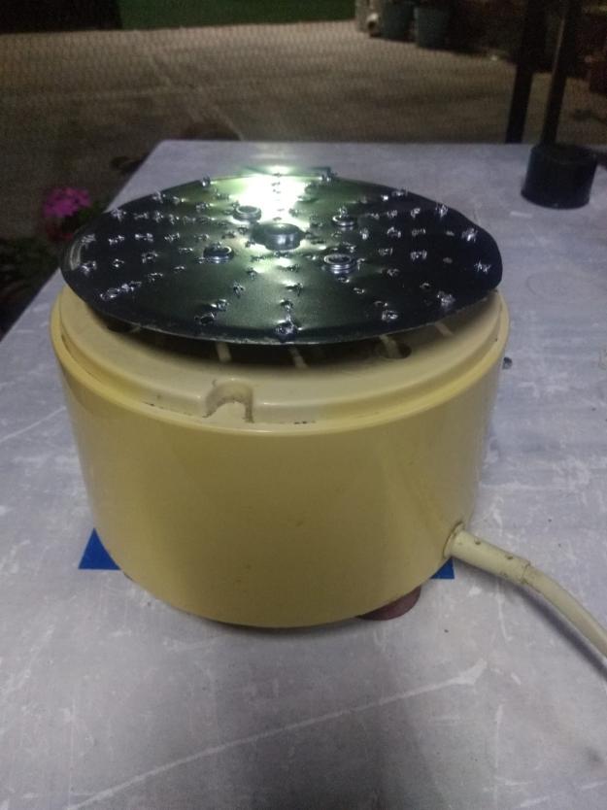
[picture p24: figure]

Imagen 1.7 Lateral del triturador

# 6. Problemas Encontrados

Problema | Impacto | Acción Correctiva
La falta de compra de la lamina para realizar la tolva. | Un poco de retraso en la realización de la tolva prototipo. | A la fecha del día de hoy ya se tiene planeado realizar la compra de la tolva.

# 7. Actividades Pendientes

Actividad | Responsable | Fecha compromiso
El armado total de la tolva hecho de lamina | Joel Flores Jiménez | Jueves 16 de Julio

# 8. Cronograma Actualizado

Estado General

☐ Adelantado

☐ Conforme al plan

☐ Retrasado

CRONOGRAMA DE ACTIVIDADES DEL PROYECTO INTEGRADOR | Adelanto | Planeado | Atraso
Fases del proyecto | Información detallada | Semana 7 | Semana 8 | Semana 9 | Semana 10 | Semana 11 | Semana 12
Fase 1: Trituradora de unicel | Ideación del modelo, lista de materiales, compra de materiales. | Avance
| Primer avance del sistema integrador de la máquina, planeación de ensamblaje de la trituradora. | | Avance
| Implementación física de la trituradora de unicel y ajuste de errores. | | | Avance
Fase 2: Mezcladora | Ideación del modelo, lista de materiales, compra de materiales. | | | Avance
| Implementación física de la mezcladora y ajuste de errores. | | | | Avance
| Primeras pruebas de mezcla y prototipado de las placas de unicel | | | | Avance
Fase 3: Sistema de mesurado | Ideación del modelo, lista de materiales, compra de materiales. | | | | | Avance
| Segundo avance del sistema integrador de la máquina. | | | | Avance
| Prototipado del modelo. | | | | | Avance
| Corrección de errores. | | | | | Avance

### Fase 4: Integración de las partes de la máquina y automatización

### Ideación de la construcción

final de la máquina. | Avance
Implementación de los tres sistemas físicos junto al sistema integrador de la máquina. | Avance
Pruebas finales de aplicación. | Avance

Justificación: En la planeación queda como pendiente la compra de la lamina en esta semana ya que se planea a mas tardar el día de mañana la compra de este ultimo material

# 9. Impacto Social y Sustentabilidad

Al crear nuestro sistema tenemos en cuenta que sea intuitivo para que la persona quien lo utilice pueda hacerlo sin ningún problema o manual detallado que indique un funcionamiento u operación del sistema complejo.

# 10. Conclusiones de la Semana

Durante esta semana se logro comprar los materiales necesarios para la realización de la tolva, así como también se realizaron distintos bosquejos para la mezcladora y por ultimo se realizó el prototipo.

# 11. Firma de Conformidad

Nombre | Firma

Líder del equipo: Joshua Philip Garrido Cervantes

Responsable de documentación: Diego Armando Morales Macias

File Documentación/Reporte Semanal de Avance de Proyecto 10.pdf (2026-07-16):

### Universidad Tecnológica Emiliano Zapata del Estado de Morelos (UTEZ)

### Técnico Superior Universitario en Automatización

Asignatura: Proyecto Integrador I

## Datos Generales

Campo | Información
Nombre del Proyecto | Diseño y desarrollo de sistema semi automático de mezcla para la elaboración de placas de cemento y unicel.
Nombre del Equipo | Los Ecolovers
Semana No. | 10
Fecha de entrega | 09 de julio de 2026
Empresa / Institución | Universidad Tecnológica Emiliano Zapata del Estado de Morelos
Profesor | Guillermo Ramírez Zuñiga
Líder del equipo | Joshua Philip Garrido Cervantes

- Se pretendía terminar la tolva hecha de lámina, ya con sus cortes.
- Lograr un avance con la misma lamina, pero en la trituradora.
- Hacer pruebas con la trituradora
- Realizar bloques de pruebas
- Diseñar y realizar los moldes nuestros bloques

## Integrantes y Participación

Integrante | Rol | Actividades realizadas esta semana | % Participación
Joshua Philip Garrido Cervantes | Líder del proyecto | Programación | 15
Diego Armando Morales Macias | Responsable de documentación | Documentación sobre los avances del proyecto | 14
Alan Suarez Fierro | Responsable de programación y calidad | Prototipo de la trituradora | 15
Galilea Jaimes Lara | Responsable de sustentabilidad e impacto social | Documentación sobre los avances del proyecto | 14
Joel Flores Jiménez | Responsable IoT y comunicaciones | Diseño de mediciones finales de la trituradora | 14
Máximo Miguel Jiménez Pérez | Responsable de electrónica | Diseño e implementación física del prototipo | 14
Jonathan Geovanni Carteras Hernández | Responsable mecánico/diseño | Diseño en 3D de la trituradora | 14

# 1. Objetivo de la Semana

Describir brevemente qué se pretendía lograr durante esta semana.

Durante esta semana no se lograron realizar avances significativos, ya que el material no llego en el tiempo como lo teníamos contemplado, pero se logró realizar un prototipo del resultado final de nuestro proyecto, haciendo moldes y haciendo mezclas con el prototipo de la trituradora que tenemos.

# 2. Actividades Programadas

Actividad | Responsable | Fecha programada | Estado (%)
Implementación de la programación al motor. | Joshua Philip Garrido Cervantes | Martes 14 de Julio | 80
Moldes para los bloques. | Alan Suárez Fierro | Viernes 10 de Julio | 100
Ensamblado de la lámina para la tolva. | Jonathan Geovanni Carteras Hernández | Lunes 13 de Julio | 50
Cortes de la lamina | Joel Flores Jiménez | Sábado 11de Julio | 50

# 3. Actividades Realizada

Describir detalladamente las actividades ejecutadas durante la semana.

# 4. Avances Técnicos

## Hardware

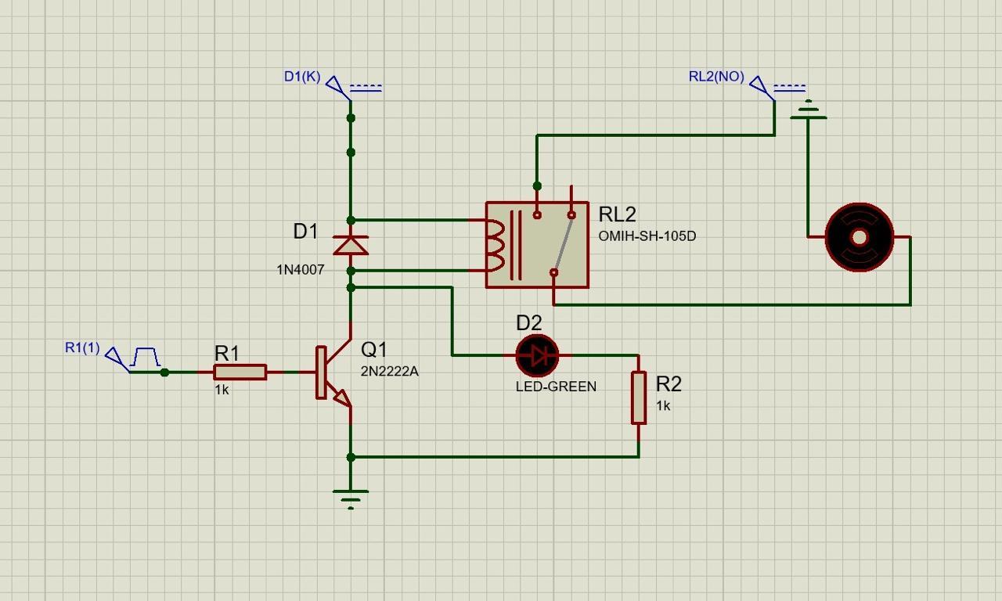
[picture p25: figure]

Imagen 1.1 simulación del motor en proteos

## Software / Programación

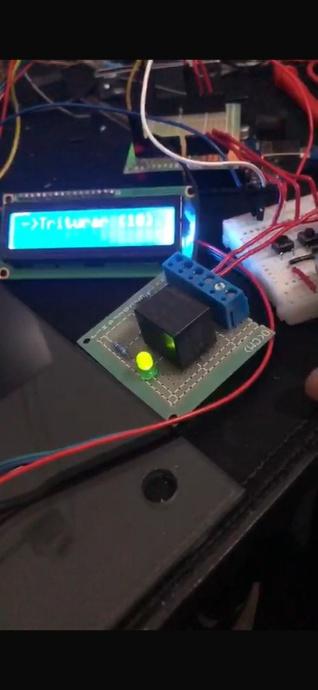
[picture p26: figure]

Imagen 1.2 Modulo del relevador.

# Diseño Mecánico


Imagen 1.3 Lamina para la tolva.

# Evidencias del Avance


Imagen 1.4 molde para la mezcla


Imagen 1.5 Moldes circulare para la mezcla.

# Evidencia y justificación


Imagen 1.6 Recibo de compra de la la

# 1. Problemas Encontrados

Problema | Impacto | Acción Correctiva
La lamina tuvo un retraso al llegar. | No se puede realizar la tolva. | Se realizarán los cortes y el ensamblado durante esta semana y la próxima.
El retraso de la lámina, retraso el ensamblado de la trituradora. | No se puede realizar la trituradora completa. | Durante la próxima semana se realizarán todos los ensamblajes y cortes correspondientes.

# 2. Actividades Pendientes

# 3. Cronograma Actualizado

Estado General

☐ Adelantado

☐ Conforme al plan

☐ Retrasado

Actividad | Responsable | Fecha compromiso
Se realzarán los cortes correspondientes para realizar el ensamblaje de la trituradora. | El ensamblaje se planea dividir en dos equipos para poder avanzar y estar al corriente con el cronograma. | Viernes 17 de Julio

CRONOGRAMA DE ACTIVIDADES DEL PROYECTO INTEGRADOR | Adelanto | Planeado | Atraso
Fases del proyecto | Información detallada | Semana 7 | Semana 8 | Semana 9 | Semana 10 | Semana 11 | Semana 12
Fase 1: Trituradora de unicel | Ideación del modelo, lista de materiales, compra de materiales. | Avance
| Primer avance del sistema integradorde la máquina, planeación de ensamblaje de la trituradora. | | Avance
| Implementación física de la trituradora de unicel y ajuste de errores. | | | Avance
Fase 2: Mezcladora | Ideación del modelo, lista de materiales, compra de materiales. | | | Avance
| Implementación física de la mezcladora y ajuste de errores. | | | | Avance
| Primeras pruebas de mezcla y prototipado de las placas de unicel | | | | Avance
Fase 3: Sistema de mesurado | Ideación del modelo, lista de materiales, compra de materiales. | | | | | Avance
| Segundo avance del sistema integradorde la máquina. | | | | Avance
| Prototipado del modelo. | | | | | Avance
| Corrección de errores. | | | | | Avance
Fase 4: Integración de las partes de la máquina y automatización | Ideación de la construcción final de la máquina. | | | | | | Avance
| Implementación de los tres sistemas físicos junto al sistema integrador de la máquina. | | | | | | Avance
| Pruebas finales de aplicación. | | | | | | Avance

Justificación: Tuvimos un retraso al realizar los avances de esta semana debido a que hubo un retraso con la entrega de la lámina, por lo cual se planea que en la siguiente semana se realicen los cortes y ensambles respectivos.

# 4. Impacto Social y Sustentabilidad

Al crear nuestro sistema tenemos en cuenta que sea intuitivo para que la persona quien lo utilice pueda hacerlo sin ningún problema o manual detallado que indique un funcionamiento u operación del sistema complejo.

# 5. Conclusiones de la Semana

Durante esta semana tuvimos retrasos con la entrega de la lamina para realizar la tolva, por lo cual no tuvimos avances significativos en esta semana.

Aunque se logro hacer el prototipo de la trituradora haciendo un bloque de muestra, estos bloques se realizaron en moldes de pvc, donde se pudo obtener el prime bloque

# 6. Firma de Conformidad

Nombre | Firma

Líder del equipo: Joshua Philip Garrido Cervantes

Responsable de documentación: Diego Armando Morales Macias

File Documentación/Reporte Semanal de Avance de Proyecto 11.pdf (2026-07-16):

### Universidad Tecnológica Emiliano Zapata del Estado de Morelos (UTEZ)

### Técnico Superior Universitario en Automatización

Asignatura: Proyecto Integrador I

## Datos Generales

Campo | Información
Nombre del Proyecto | Diseño y desarrollo de sistema semi automático de mezcla para la elaboración de placas de cemento y unicel.
Nombre del Equipo | Los Ecolovers
Semana No. | 11
Fecha de entrega | 16 de Junio de 2026
Empresa / Institución | Universidad Tecnológica Emiliano Zapata del Estado de Morelos
Profesor | Guillermo Ramírez Zuñiga
Líder del equipo | Joshua Philip Garrido Cervantes

- Realizar los cortes correspondientes a la tolva de la trituradora.
- Realización de pruebas de dureza del primer bloque.
- Realizar un dispensador automático para el material de prototipo.

## Integrantes y Participación

Integrante | Rol | Actividades realizadas esta semana | % Participación
Joshua Philip Garrido Cervantes | Líder del proyecto | Realización de prototipo de dispensador de material. | 15
Diego Armando Morales Macias | Responsable de documentación | Realización de reporte semanal. | 14
Alan Suarez Fierro | Responsable de programación y calidad | Pruebas de dureza del bloque. | 15
Galilea Jaimes Lara | Responsable de sustentabilidad e impacto social | Realización del reporte semanal | 14
Joel Flores Jiménez | Responsable IoT y comunicaciones | Cortes de lámina para la tolva. | 14
Máximo Miguel Jiménez Pérez | Responsable de electrónica | Realización de prototipo de dispensador de material. | 14
Jonathan Geovanni Carteras Hernández | Responsable mecánico/diseño | Calculo de medidas para el corte de la lámina. | 14

# 1. Objetivo de la Semana

Describir brevemente qué se pretendía lograr durante esta semana.

Durante esta semana se realizaron los cortes para realizar la tolva de la trituradora final, los cortes se hicieron respecto a los bocetos que ya se tenían previamente.
Se implemento al código mas orden con respecto a las variables.
Se agrego interrupción externa al código para mejor manejo de interfaz física con botones

# 2. Actividades Programadas

Actividad | Responsable | Fecha programada | Estado (%)
Ensamblado de la tolva | Joel Flores Jiménez | Jueves 23 de Julio | 50
Ensamblado de la trituradora | Jonathan Carteras Hernández | Jueves 23 de Julio | 50
Ensamblado de la mezcladora | Galilea Jaimes Lara | Jueves 23 de Julio | 60
Implementación de dispensador de material | Joshua Philip Garrido Cervantes | Viernes 24 de Julio | 60
Armado de moldes para la mezcla | Alan Suarez Fierro | Viernes 24 de Julio | 80

# 3. Actividades Realizadas

Describir detalladamente las actividades ejecutadas durante la semana

# 4. Avances Técnicos

## Software / Programación


Figura 1.1 Código con interrupción externa para mejor manejo de interfaz

# 5. Evidencias del Avance


Figura 1.2 Prototipo de dispensador de material

Figura 1.3 lamina cortada, para el armado de la tolva.

# 6. Problemas Encontrados

Por el momento no hemos contado con problemas, durante esta semana.

# 7. Actividades Pendientes

Actividad | Responsable | Fecha compromiso
Ensamble de la trituradora completa. | Joel Flores Jiménez | Jueves 23 de Julio.
Ensamble de la mezcladora completa | Jaimes Lara Galilea | Jueves 23 de Julio.

# 8. Cronograma Actualizado

Estado General

☐ Adelantado

☐ Conforme al plan

☐ Retrasado

CRONOGRAMA DE ACTIVIDADES DEL PROYECTO INTEGRADOR | Adelanto | Planeado | Atraso
Fases del proyecto | Información detallada | Semana 7 | Semana 8 | Semana 3 | Semana 10 | Semana 11 | Semana 12
Fase 1: Trituradora de unicel | Ideación del modelo, lista de materiales, compra de materiales. | Avance
| Primer avance del sistema integradorde la máquina, planeación de ensamblaje de la trituradora. | | Avance
| Implementación física de la trituradora de unicel y ajuste de errores. | | | Avance
Fase 2: Mezcladora | Ideación del modelo, lista de materiales, compra de materiales. | | | Avance
| Implementación física de la mezcladora y ajuste de errores. | | | | Avance
| Primeras pruebas de mezcla y prototipado de las placas de unicel | | | | Avance
Fase 3: Sistema de mesurado | Ideación del modelo, lista de materiales, compra de materiales. | | | | | Avance
| Segundo avance del sistema integradorde la máquina. | | | | Avance
| Prototipado del modelo. | | | | | Avance
| Corrección de errores. | | | | | Avance
Fase 4: Integración de las partes de la máquina y automatización | Ideación de la construcción final de la máquina. | | | | | | Avance
| Implementación de los tres sistemas físicos junto al sistema integrador de la máquina. | | | | | | Avance
| Pruebas finales de aplicación. | | | | | | Avance

Justificación: Por el momento la implementación física va en el orden propuesto para su realización se espera que dentro de la próxima semana la construcción de la trituradora y la

# 9. Impacto Social y Sustentabilidad

Al crear nuestro sistema tenemos en cuenta que sea intuitivo para que la persona quien lo utilice pueda hacerlo sin ningún problema o manual detallado que indique un funcionamiento u operación del sistema complejo.

# 10. Conclusiones de la Semana

Durante esta semana se realizaron los cortes para la tolva de la trituradora, para en la siguiente semana construir la trituradora completa final.

Aparte en esta emana se realizo un dispensador de material, para ser agregado a la trituradora.

# 11. Firma de Conformidad

Nombre | Firma

Líder del equipo: Joshua Philip Garrido Cervantes

Responsable de documentación: Diego Armando Morales Macias

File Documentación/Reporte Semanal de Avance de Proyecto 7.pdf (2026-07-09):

### Universidad Tecnológica Emiliano Zapata del Estado de Morelos (UTEZ)

### Técnico Superior Universitario en Automatización

Asignatura: Proyecto Integrador I

## Datos Generales

Campo | Información
Nombre del Proyecto | Diseño y desarrollo de sistema semi automático de mezcla para la elaboración de placas de cemento y unicel.
Nombre del Equipo | Los Ecolovers
Semana No. | 7
Fecha de entrega | 18 de junio de 2026
Empresa / Institución | Universidad Tecnológica Emiliano Zapata del Estado de Morelos
Profesor | Guillermo Ramírez Zuñiga
Líder del equipo | Joshua Philip Garrido Cervantes

## Integrantes y Participación

Integrante | Rol | Actividades realizadas esta semana | % Participación
Joshua Philip Garrido Cervantes | Líder del proyecto | Bosquejos y diseños preliminares | 15
Diego Armando Morales Macias | Responsable de documentación | Documentación sobre los avances del proyecto | 15
Alan Suarez Fierro | Responsable de programación y calidad | Bosquejos e ideas sobre la planeación del proyecto | 15
Galilea Jaimes Lara | Responsable de sustentabilidad e impacto social | Documentación sobre los avances del proyecto. | 15
Joel Jiménez Flores | Responsable IoT y comunicaciones | Investigación sobre los materiales a ocupar y necesitar. | 15
Máximo Miguel Jiménez Pérez | Responsable de electrónica | Investigación sobre los materiales a ocupar y necesitar | 10
Jonathan Geovanni Carteras Hernández | Responsable mecánico/diseño | Diseños sobre el proyecto | 15

# 1. Objetivo de la Semana

Describir brevemente qué se pretendía lograr durante esta semana.

- Diseñar propuestas para la construcción de la trituradora de unicel
- Definir materia prima e insumos para el ensamblaje de la trituradora con base a costos, accesibilidad de material, operación del material e impacto ambiental.
- Definir un presupuesto inicial de los recursos/materiales que son requeridos

# 2. Actividades Programadas

Actividad | Responsable | Fecha programada | Estado (%)
Diseños preliminares | Carteras Hernández Jonathan | Miércoles 17 de junio | 100
Bosquejos | Garrido Cervantes Joshua Philip | Lunes 15 de junio | 100
Investigación de materiales | Flores Jiménez Joel | Miércoles 17 de junio | 75

# 3. Actividades Realizadas

Describir detalladamente las actividades ejecutadas durante la semana.

Durante esta semana se realizaron diseños en 3D en el software de SolidWorks, estos diseños realizaron con el fin de tener una visión y un punto de apoyo sobre cómo será nuestro prototipo de la trituradora de unicel.
También se realizó la investigación sobre los distintos componentes para la trituradora, que se piensan utilizar, así también se realizó un presupuesto límite para obtener los materiales necesarios.

# 4. Avances Técnicos

## Diseño Mecánico


Se realizaron modelados en 3D del prototipo.
Estos diseños nos permiten ver como implementaremos los elementos y mecanismos en nuestro diseño final o en el prototipo.


Se realizaron modelados en 3D del prototipo.

Estos diseños nos permiten ver como implementaremos los elementos y mecanismos en nuestro diseño final o en el prototipo.

# 5. Evidencias del Avance



Estos son algunos de lo materiales que ocuparemos para realizar el prototipo funcional, los precios pueden variar según donde se encuentren.

# 6. Problemas Encontrados

Problema | Impacto | Acción Correctiva
Ciertas partes de los modelados 3D no se tenía conocimiento de cómo realizarlas. | Perjudico en el tiempo nada más. | Se realizaron diferentes modelos.

# 7. Actividades Pendientes

Actividad | Responsable | Fecha compromiso
Adquirir el material con los proveedores seleccionados. | Serán adquiridos entre todo el equipo. | Jueves, 25 de junio.
Armar el sistema de triturado. | Todo el equipo completo realizara el sistema. | Jueves, 2 de Julio.
Realizar pruebas. | Entre dos o tres integrantes del equipo realizaran las pruebas pertinentes. | Viernes, 3 de Julio

# 8. Cronograma Actualizado

Indicar si existe retraso, adelanto o cumplimiento respecto al plan original.

Estado General

☐ Adelantado

☐ Conforme al plan

☐ Retrasado

Justificación:

Es importante definir la cantidad de material a utilizar, así como los insumos que se requieren (como motores, engranes, valeros, etc.) Para que antes de empezar con la construcción física no se compre material de sobra y tampoco que haga falta.

Así como definir un objetivo al que el equipo se pueda centrar, definir responsabilidades y compromisos.

# 9. Impacto Social y Sustentabilidad

En este avance logramos tener una eficiencia en la cantidad de recursos que se piensa utilizar, ya que algunos son reciclados y son de muy bajo costo, para su implementación.

# 10. Conclusiones de la Semana

Los avances realizados son las bases fundamentales para que el proyecto pueda realizarse de la mejor manera posible, también como nos ayuda a tener una vista más clara de los elementos que necesitaremos para realizarlo.

# 11. Firma de Conformidad

Nombre | Firma

Líder del equipo:

Responsable de documentación:

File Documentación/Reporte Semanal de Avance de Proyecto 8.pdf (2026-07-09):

### Universidad Tecnológica Emiliano Zapata del Estado de Morelos (UTEZ)

### Técnico Superior Universitario en Automatización

Asignatura: Proyecto Integrador I

## Datos Generales

Campo | Información
Nombre del Proyecto | Diseño y desarrollo de sistema semi automático de mezcla para la elaboración de placas de cemento y unicel.
Nombre del Equipo | Los Ecolovers
Semana No. | 8
Fecha de entrega | 25 de junio de 2026
Empresa / Institución | Universidad Tecnológica Emiliano Zapata del Estado de Morelos
Profesor | Guillermo Ramírez Zuñiga
Líder del equipo | Joshua Philip Garrido Cervantes

## Integrantes y Participación

Integrante | Rol | Actividades realizadas esta semana | % Participación
Joshua Philip Garrido Cervantes | Líder del proyecto | Bosquejos y diseños preliminares | 15
Diego Armando Morales Macias | Responsable de documentación | Documentación sobre los avances del proyecto | 14
Alan Suarez Fierro | Responsable de programación y calidad | Lógica de programación del sistema integrador | 15
Galilea Jaimes Lara | Responsable de sustentabilidad e impacto social | Documentación sobre los avances del proyecto | 14
Joel Flores Jiménez | Responsable IoT y comunicaciones | Diseño de mediciones finales de la trituradora | 14
Máximo Miguel Jiménez Pérez | Responsable de electrónica | Diseño e implementación física del prototipo | 14
Jonathan Geovanni Carteras Hernández | Responsable mecánico/diseño | Ideación preliminar del sistema integrador | 14

# 1. Objetivo de la Semana

Describir brevemente qué se pretendía lograr durante esta semana.

- Lograr en simulación un primer avance del sistema integrador donde el usuario pueda interactuar con controles físicos.
- Presentar las medidas finales físicas que tendrá la trituradora
- Implementar físicamente el prototipo del sistema integrador funcional a sus primeras limitaciones.

# 2. Actividades Programadas

Actividad | Responsable | Fecha programada | Estado (%)
Diseño de sistema integrador | Máximo Miguel Jiménez Pérez | Lunes 21 de Julio | 100
Obtención de material de práctica | Joshua Philip Garrido Cervantes | Martes 23 de Julio | 100
Implementación física del prototipo del sistema | Alan Suárez Fierro | Miércoles 24 de Julio | 90
Diseño de tolva | Jonathan Geovanni Carteras Hernández | Martes 23 de Julio | 100
Diseño de escala y medidas de trituradora | Joel Flores Jiménez | Miércoles 24 de Julio | 100

# 3. Actividades Realizadas

Describir detalladamente las actividades ejecutadas durante la semana.

Durante esta semana se hizo el primer avance para el cerebro de nuestra máquina, el sistema integrador. Su funcionalidad radica en probar y testear las diferentes partes de la máquina por separado.
Además, se definió la escala y medidas finales de la trituradora de unicel, además de presentar un nuevo complemento para esta, la tolva de la trituradora.

# 4. Avances Técnicos

## Hardware


Figura 1.1: Hardware a utilizar en el prototipo del sistema integrador.

Lista:
- (3) Pulsadores
- (1) LED color rojo
- (1) Display LCD 16x2
- (1) Módulo I2C para LCD
- (1) Transistor NPN 2N2222

## Software / Programación


Figura 2.1: circuito simulado en TINKERCAD del sistema integrador.

Figura 2.2: Fragmento de código de programación del microcontrolador.

## Diseño Mecánico


Figura 3.1: Tolva desde vista planta, cotas en cm.


Figura 3.2: Tolva desde vista alzado, cotas en cm.

Figura 3.3: Tolva desde vista isométrica.


Figura 3.4: Diseño preliminar final de la trituradora con tolva integrada en vista isométrica.

# 5. Evidencias del Avance


Figura 4.1: Diseño e ideación del sistema integrador.


Figura 4.2: Armado físico del sistema integrador.


Figura 4.3: Funcionamiento del sistema integrador (led encendido durante 3 segundos)


Figura 4.4: Diseño final de medidas del triturador de unicel.

# 6. Problemas Encontrados

Problema | Impacto | Acción Correctiva
Arduino no reconocido por el IDE. | No se puede cargar el sistema al Arduino. | Búsqueda de controladores necesarios, cambio de cable de datos.
Pantalla LCD no cargaba los caracteres. | El sistema queda “ciego” al no poder ver que funcionaba. | Instalación de librerías adicionales para el módulo I2C.

# 7. Actividades Pendientes

Actividad | Responsable | Fecha compromiso
Conectar motor CD y probar funcionamiento con una fuente de alimentación externa. | Joshua Philip Garrido Cervantes | Lunes 29 de Julio.

# 8. Cronograma Actualizado

Estado General

☐ Adelantado

☐ Conforme al plan

☐ Retrasado

CRONOGRAMA DE ACTIVIDADES DEL PROYECTO INTEGRADOR | Adelanto | Planeado | Atraso
Fases del proyecto | Información detallada | Semana 7 | Semana 8 | Semana 9 | Semana 10 | Semana 11 | Semana 12
Fase 1: Trituradora de unicel | Ideación del modelo, lista de materiales, compra de materiales. | Avance
| Primer avance del sistema integrador de la máquina, planeación de ensamblaje de la trituradora. | | Avance
| Implementación física de la trituradora de unicel y ajuste de errores. | | | Avance
Fase 2: Mezcladora | Ideación del modelo, lista de materiales, compra de materiales. | | | Avance
| Implementación física de la mezcladora y ajuste de errores. | | | | Avance
| Primeras pruebas de mezcla y prototipado de las placas de unicel | | | | Avance
Fase 3: Sistema de mesurado | Ideación del modelo, lista de materiales, compra de materiales. | | | | | Avance
| Segundo avance del sistema integrador de la máquina. | | | | Avance
| Prototipado del modelo. | | | | | Avance
| Corrección de errores. | | | | | Avance
Fase 4: Integración de las partes de la máquina y automatización | Ideación de la construcción final de la máquina. | | | | | | Avance
| Implementación de los tres sistemas físicos junto al sistema integrador de la máquina. | | | | | | Avance
| Pruebas finales de aplicación. | | | | | | Avance

Justificación: En la planeación dejamos pendiente la implementación física de la trituradora para poder dar inicio la creación del sistema que controlará la máquina, incluyendo la trituradora. Así nos aseguramos de contar con todo el material en tiempo y forma para su posterior trabajo para armar la trituradora.

# 9. Impacto Social y Sustentabilidad

Al crear nuestro sistema tenemos en cuenta que sea intuitivo para que la persona quien lo utilice pueda hacerlo sin ningún problema o manual detallado que indique un funcionamiento u operación del sistema complejo.

# 10. Conclusiones de la Semana

Durante esta semana se logró idear, diseñar e implementar físicamente el sistema integrador de nuestro proyecto. Así mismo al mismo tiempo se trabajaron medidas finales de la trituradora además de agregar una nueva parte al modelo que fue seleccionado para su implementación física.

# 11. Firma de Conformidad

Nombre | Firma

Líder del equipo: Joshua Philip Garrido Cervantes

Responsable de documentación: Diego Armando Morales Macias

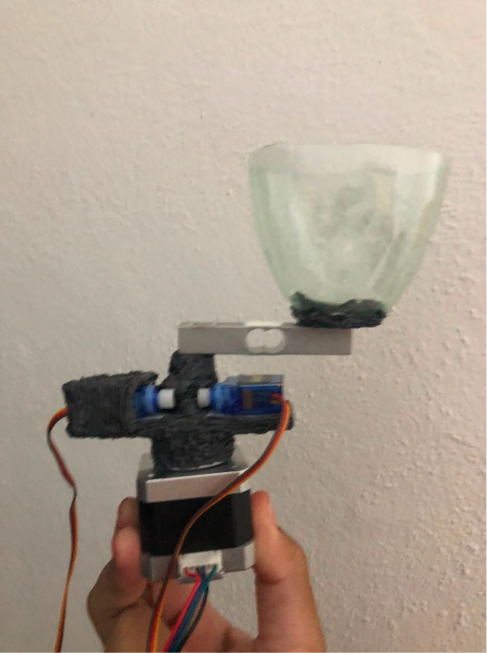
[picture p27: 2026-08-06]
Imágenes/Brazo dosificador .png

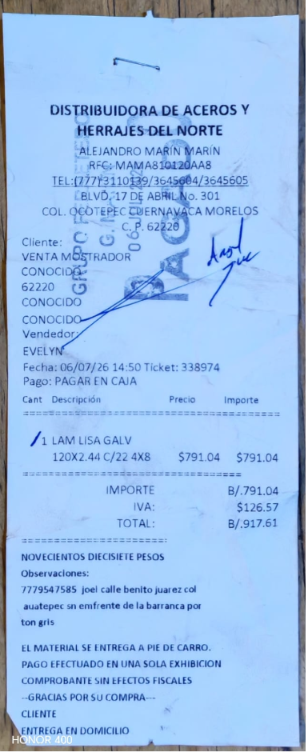
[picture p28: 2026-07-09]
Imágenes/Recibo lamina.png

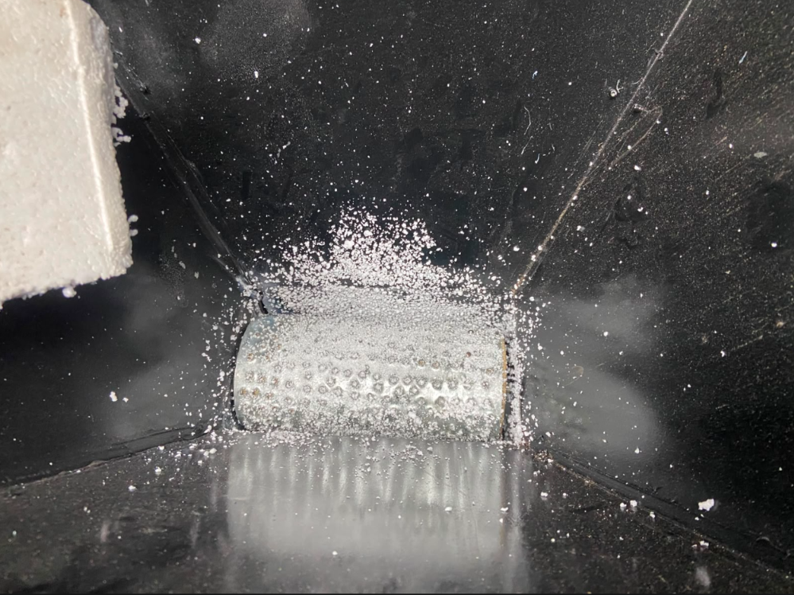
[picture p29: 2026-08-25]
Imágenes/Trituradora de unicel en funcionamiento.png

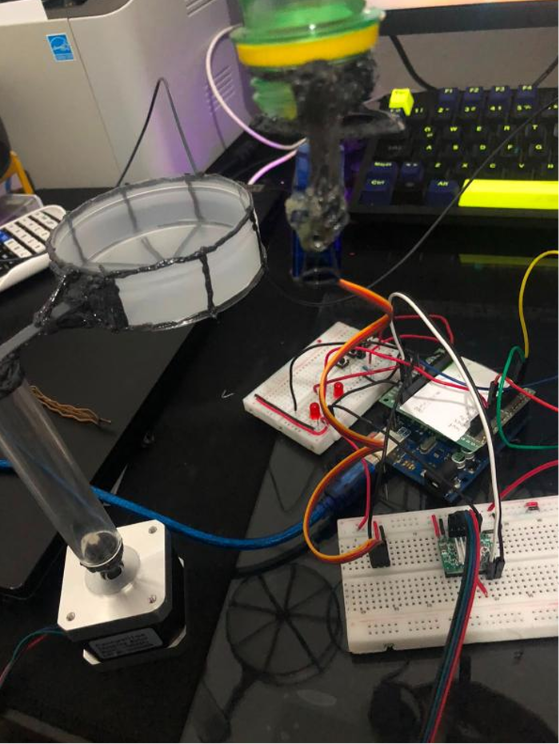
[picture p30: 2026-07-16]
Imágenes/Prototipo dispensador con recolector.png

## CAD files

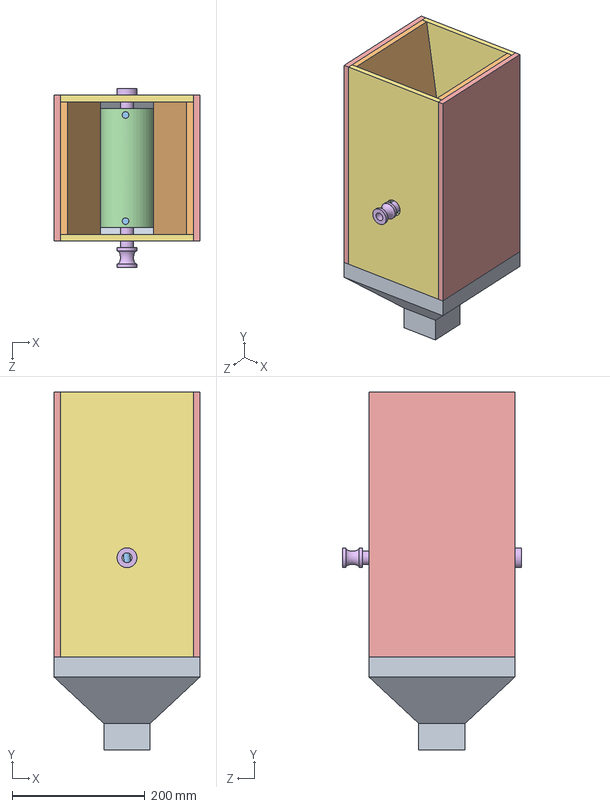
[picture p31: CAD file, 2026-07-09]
CAD/Ensamblaje.SLDASM
220.0 x 540.0 x 270.0 mm
Pared_Agujero x 2
Eje_Rodillo
Pared_Normal x 2
Rodillo
Seguro x 2
Pared_Inclinada x 2
Tolva

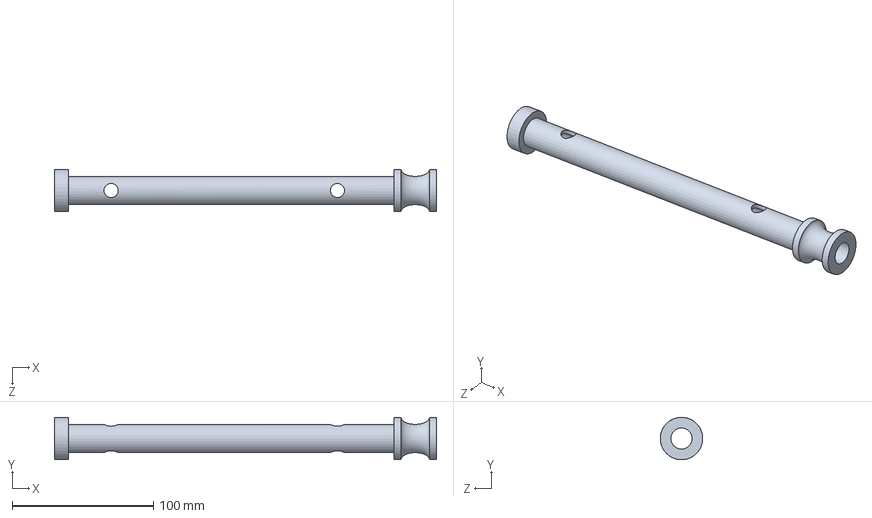
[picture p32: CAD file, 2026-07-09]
CAD/Eje_Rodillo.SLDPRT
270.0 x 30.0 x 30.0 mm

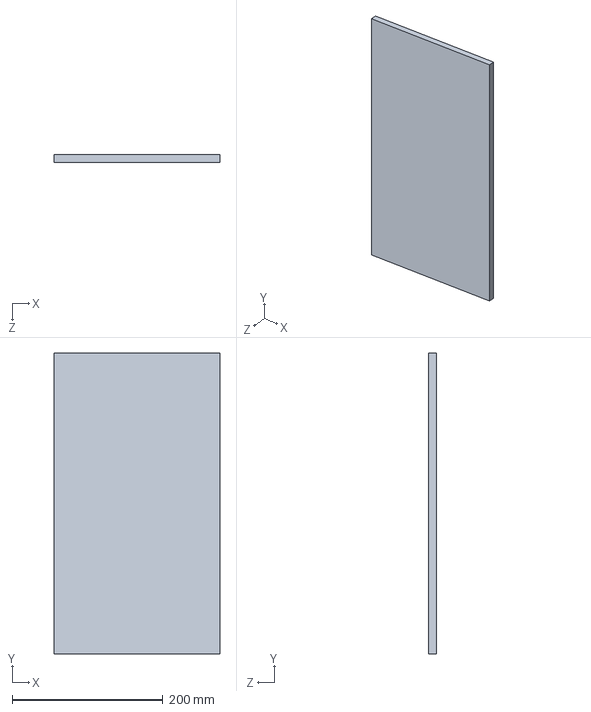
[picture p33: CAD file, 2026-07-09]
CAD/Pared_Normal.SLDPRT
220.0 x 400.0 x 10.0 mm

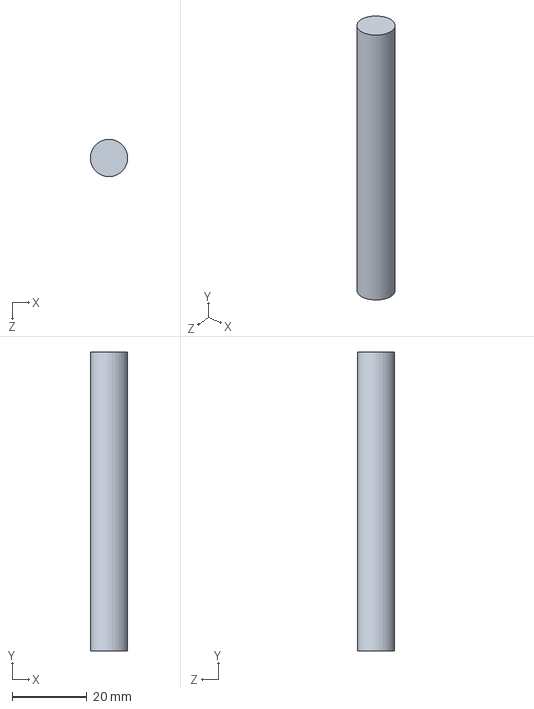
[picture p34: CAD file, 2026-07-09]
CAD/Seguro.SLDPRT
10.0 x 80.0 x 10.0 mm

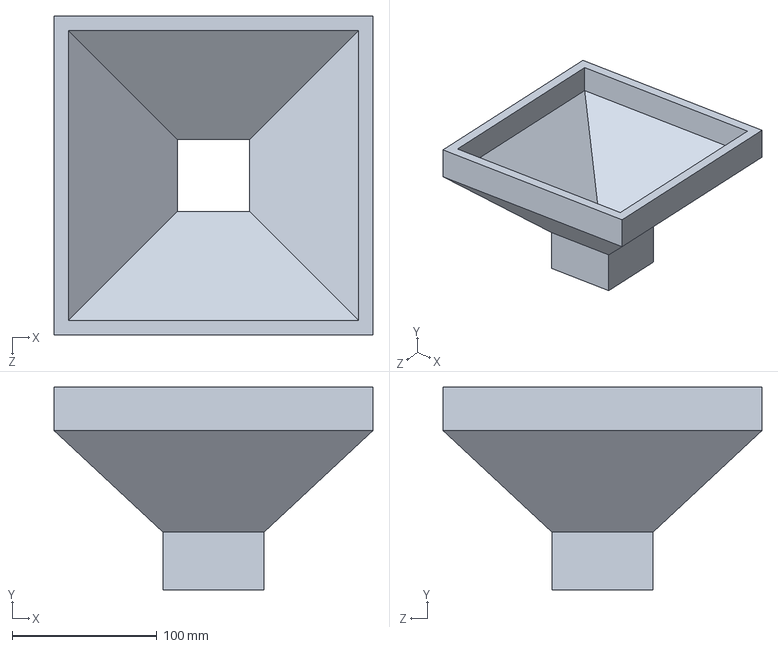
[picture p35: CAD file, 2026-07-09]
CAD/Tolva.SLDPRT
220.0 x 140.0 x 220.0 mm

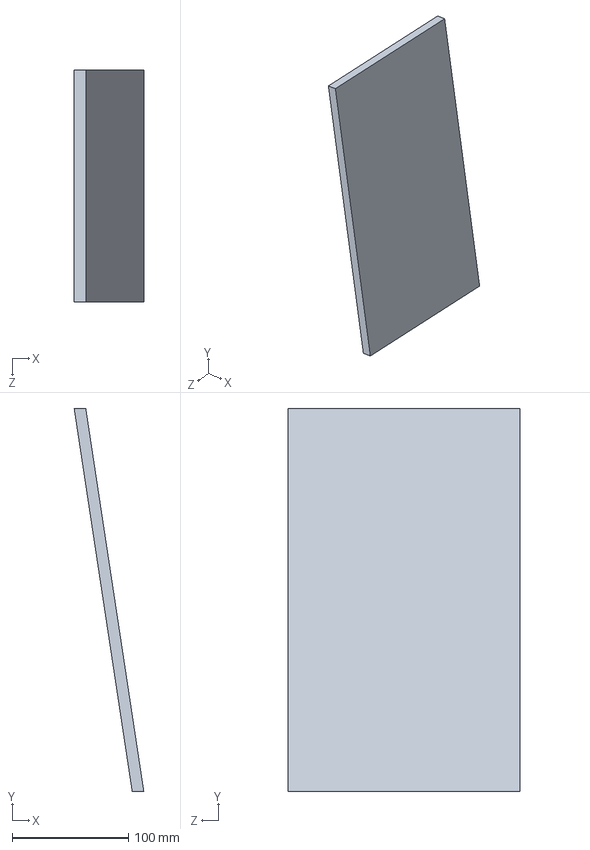
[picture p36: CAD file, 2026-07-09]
CAD/Pared_Inclinada.SLDPRT
60.0 x 330.0 x 200.0 mm

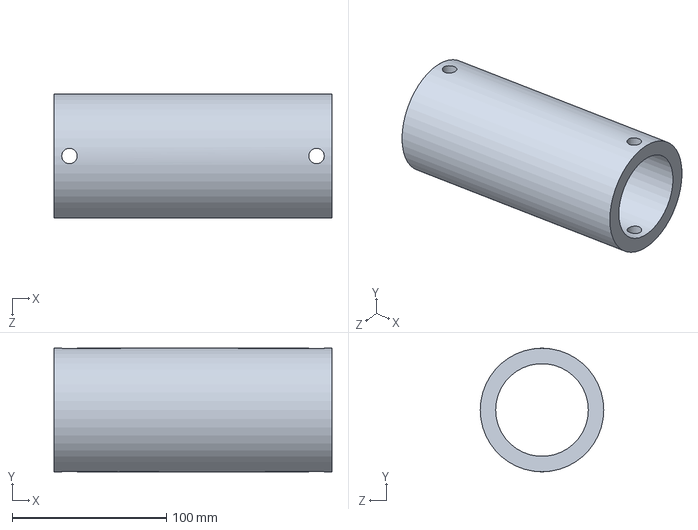
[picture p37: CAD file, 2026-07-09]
CAD/Rodillo.SLDPRT
180.0 x 80.0 x 80.0 mm

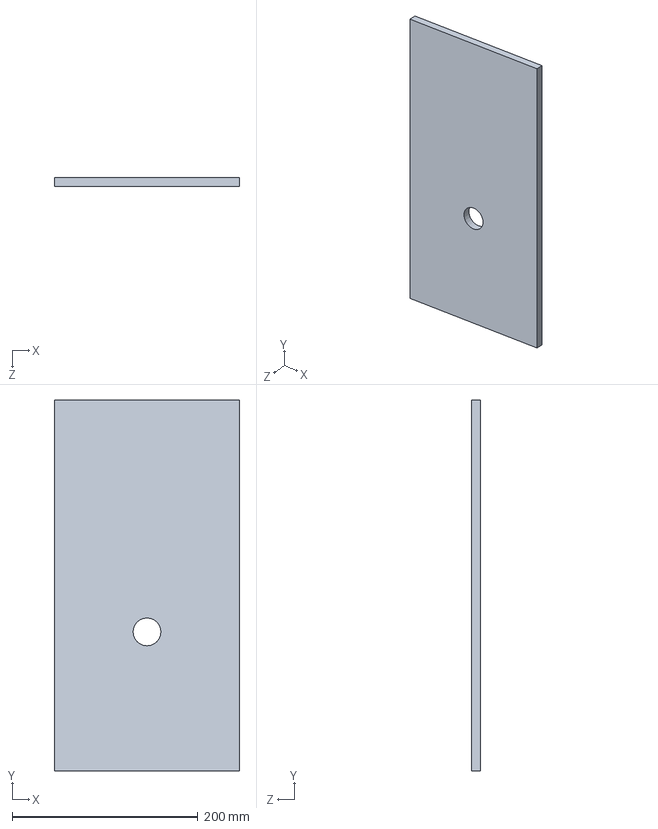
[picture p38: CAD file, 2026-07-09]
CAD/Pared_Agujero.SLDPRT
200.0 x 400.0 x 10.0 mm

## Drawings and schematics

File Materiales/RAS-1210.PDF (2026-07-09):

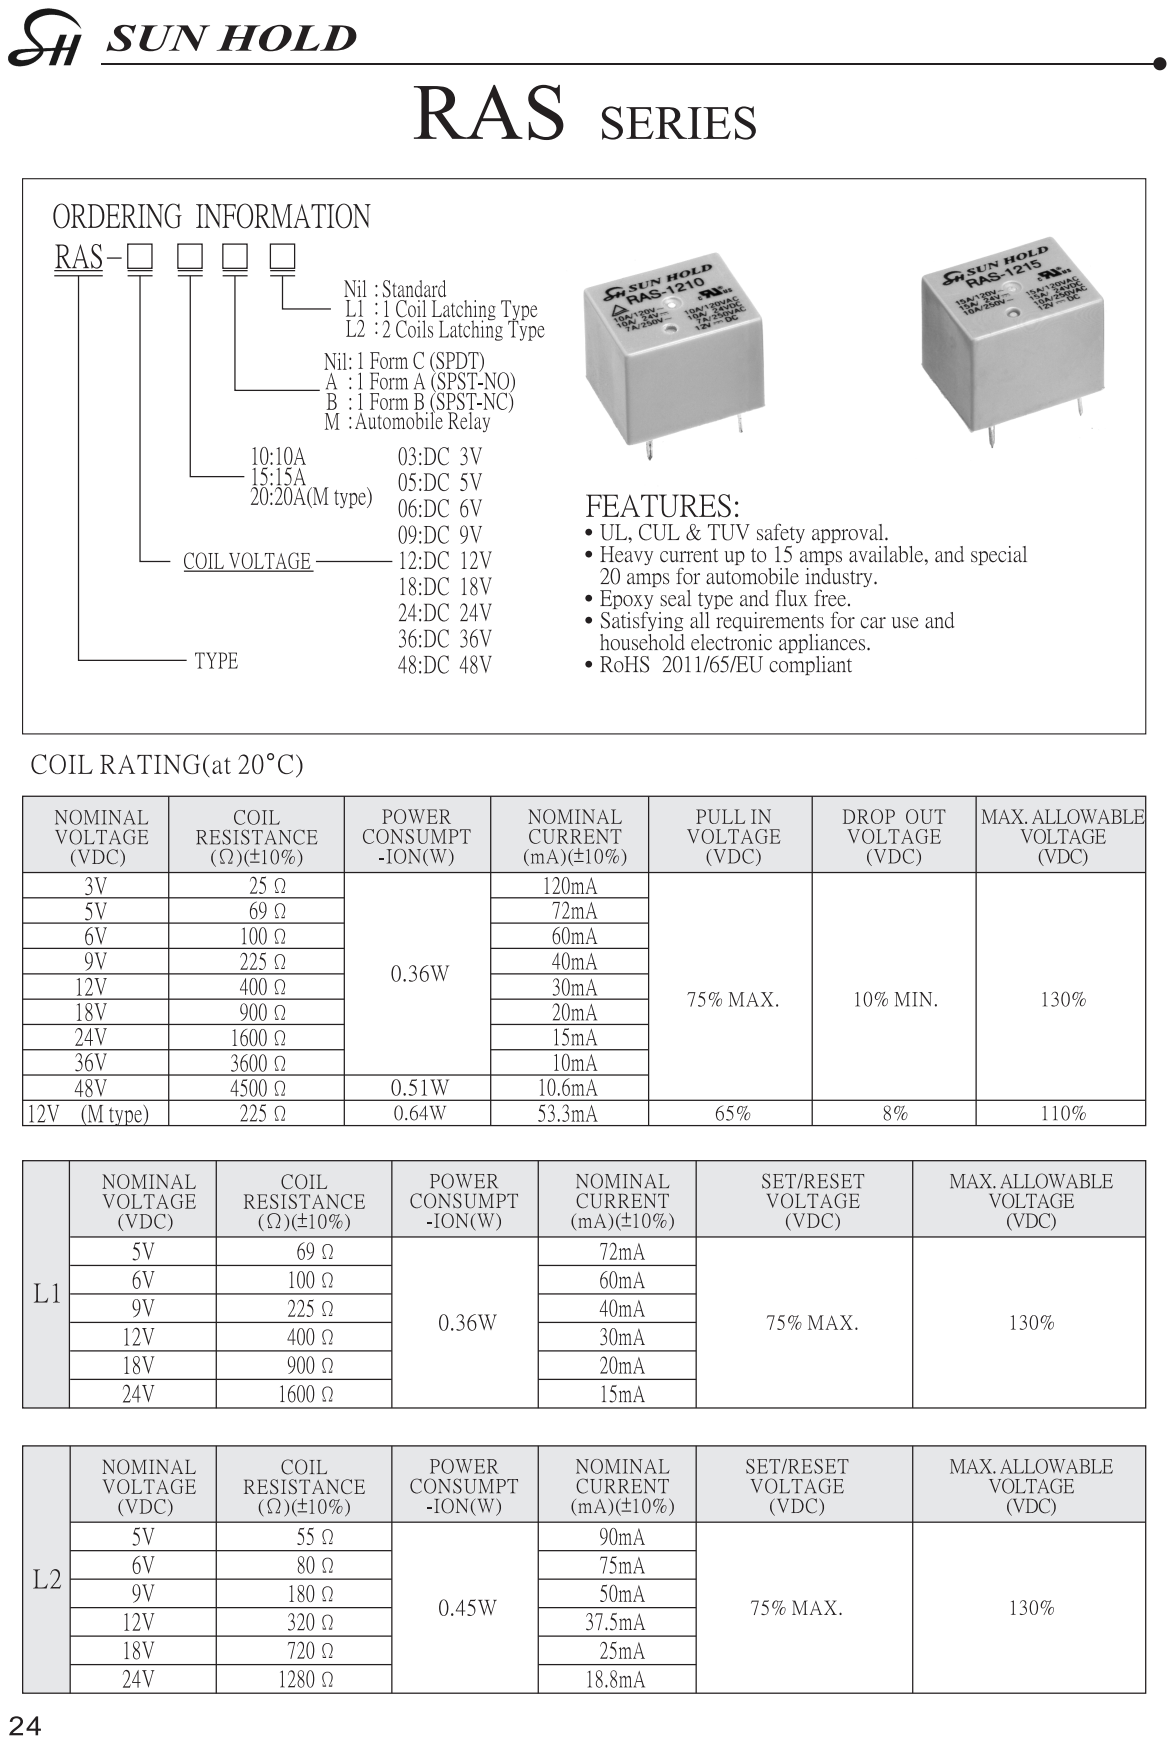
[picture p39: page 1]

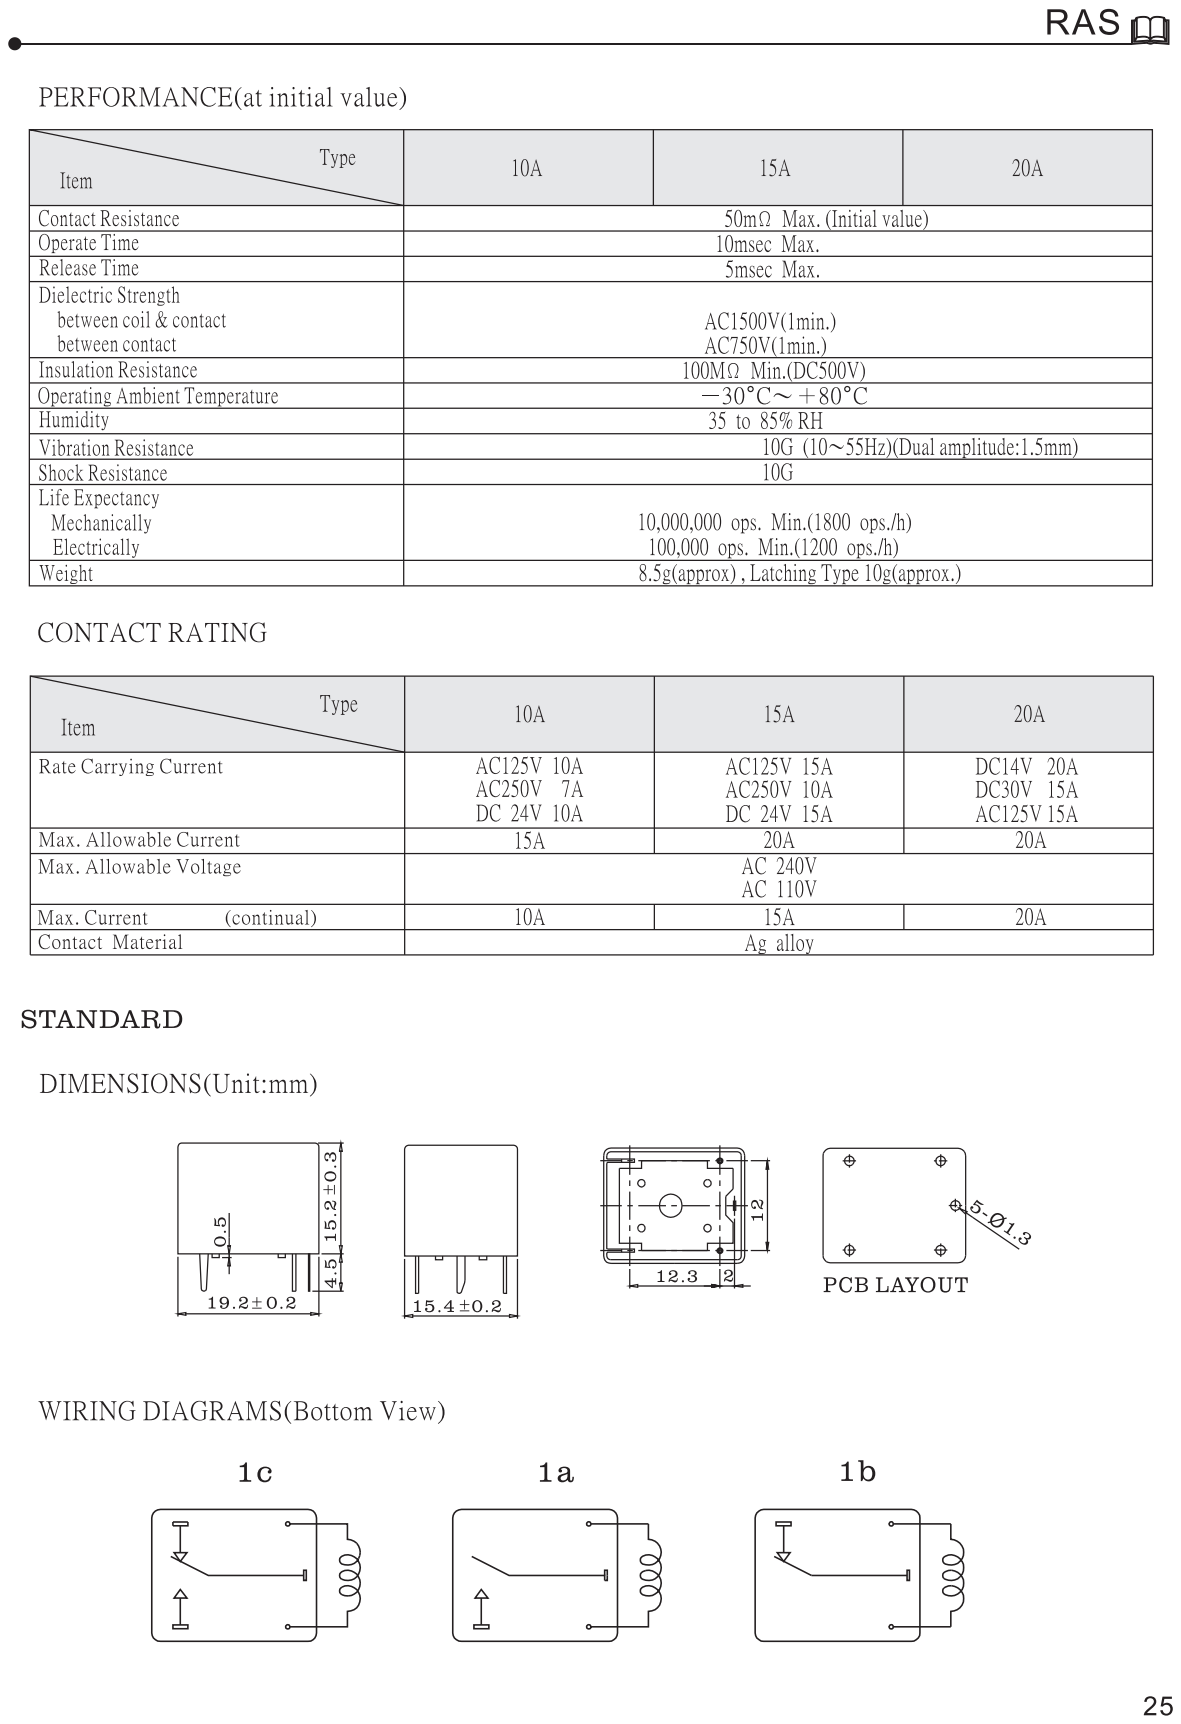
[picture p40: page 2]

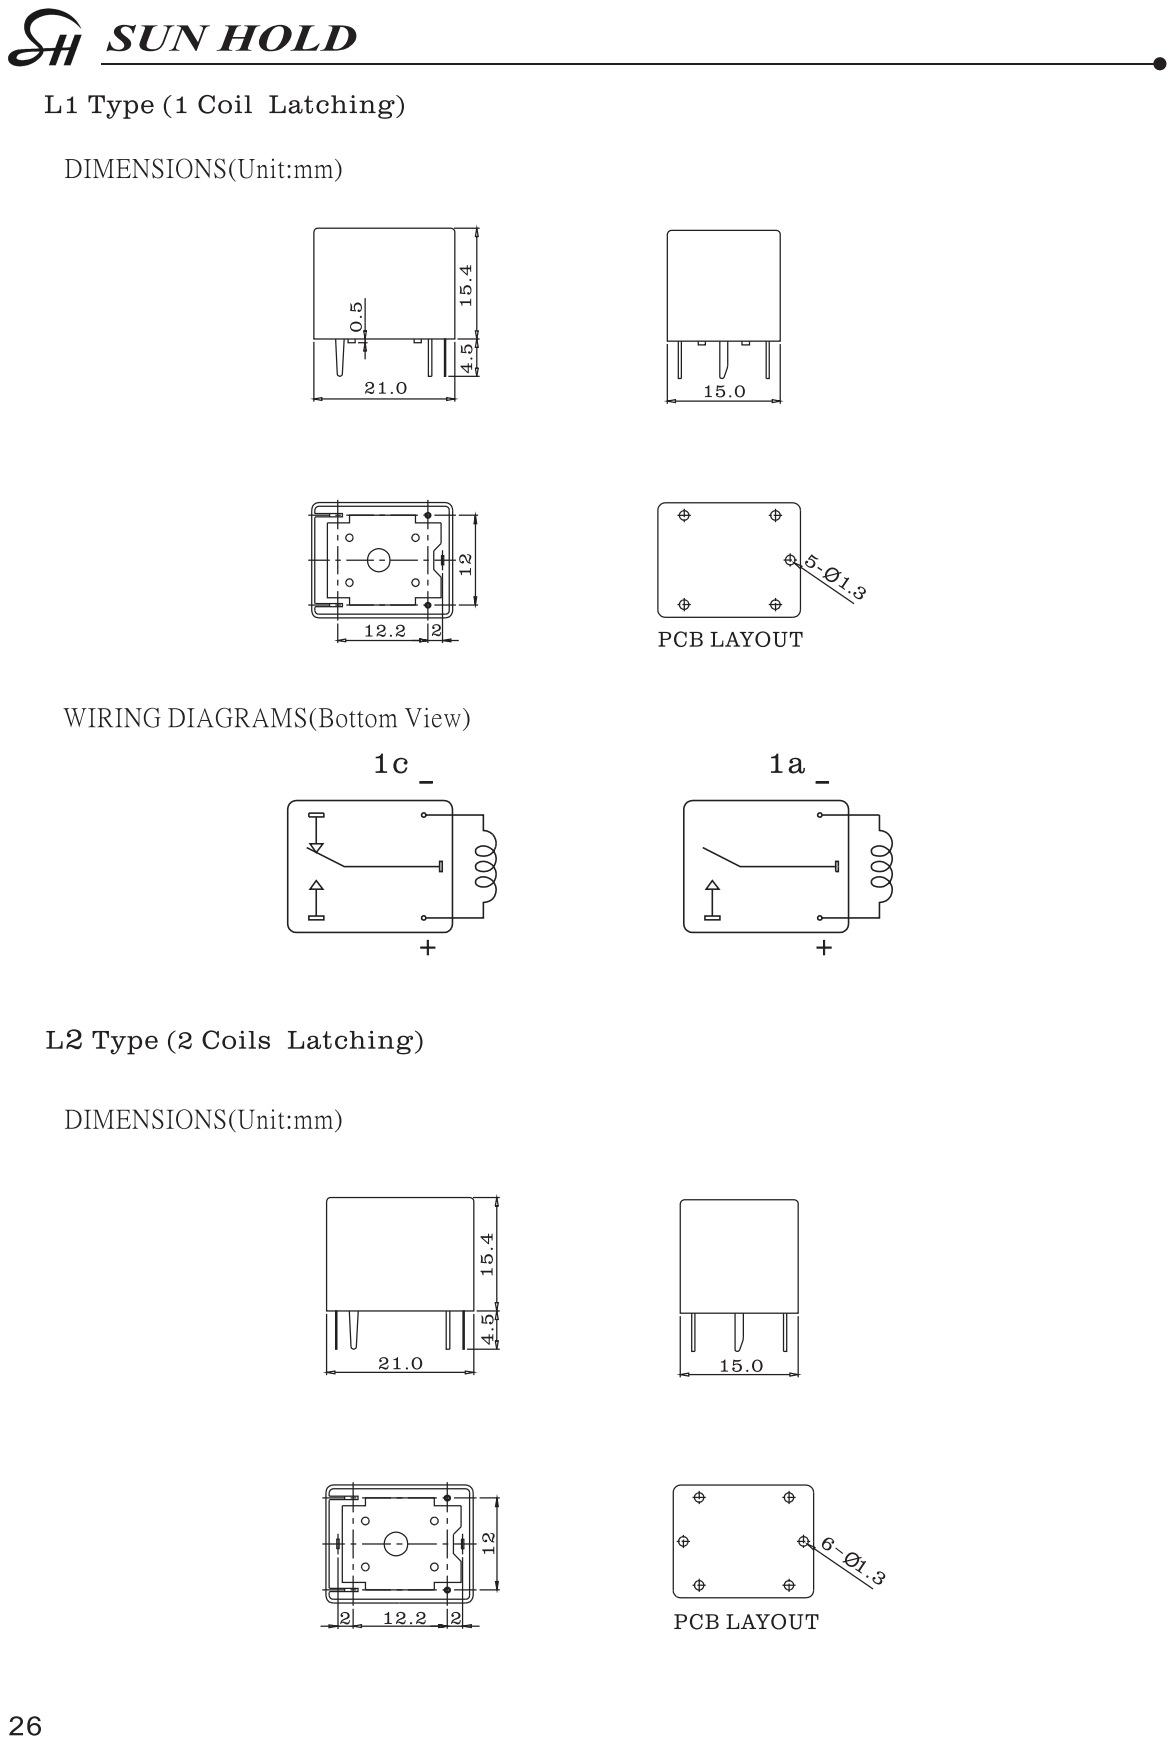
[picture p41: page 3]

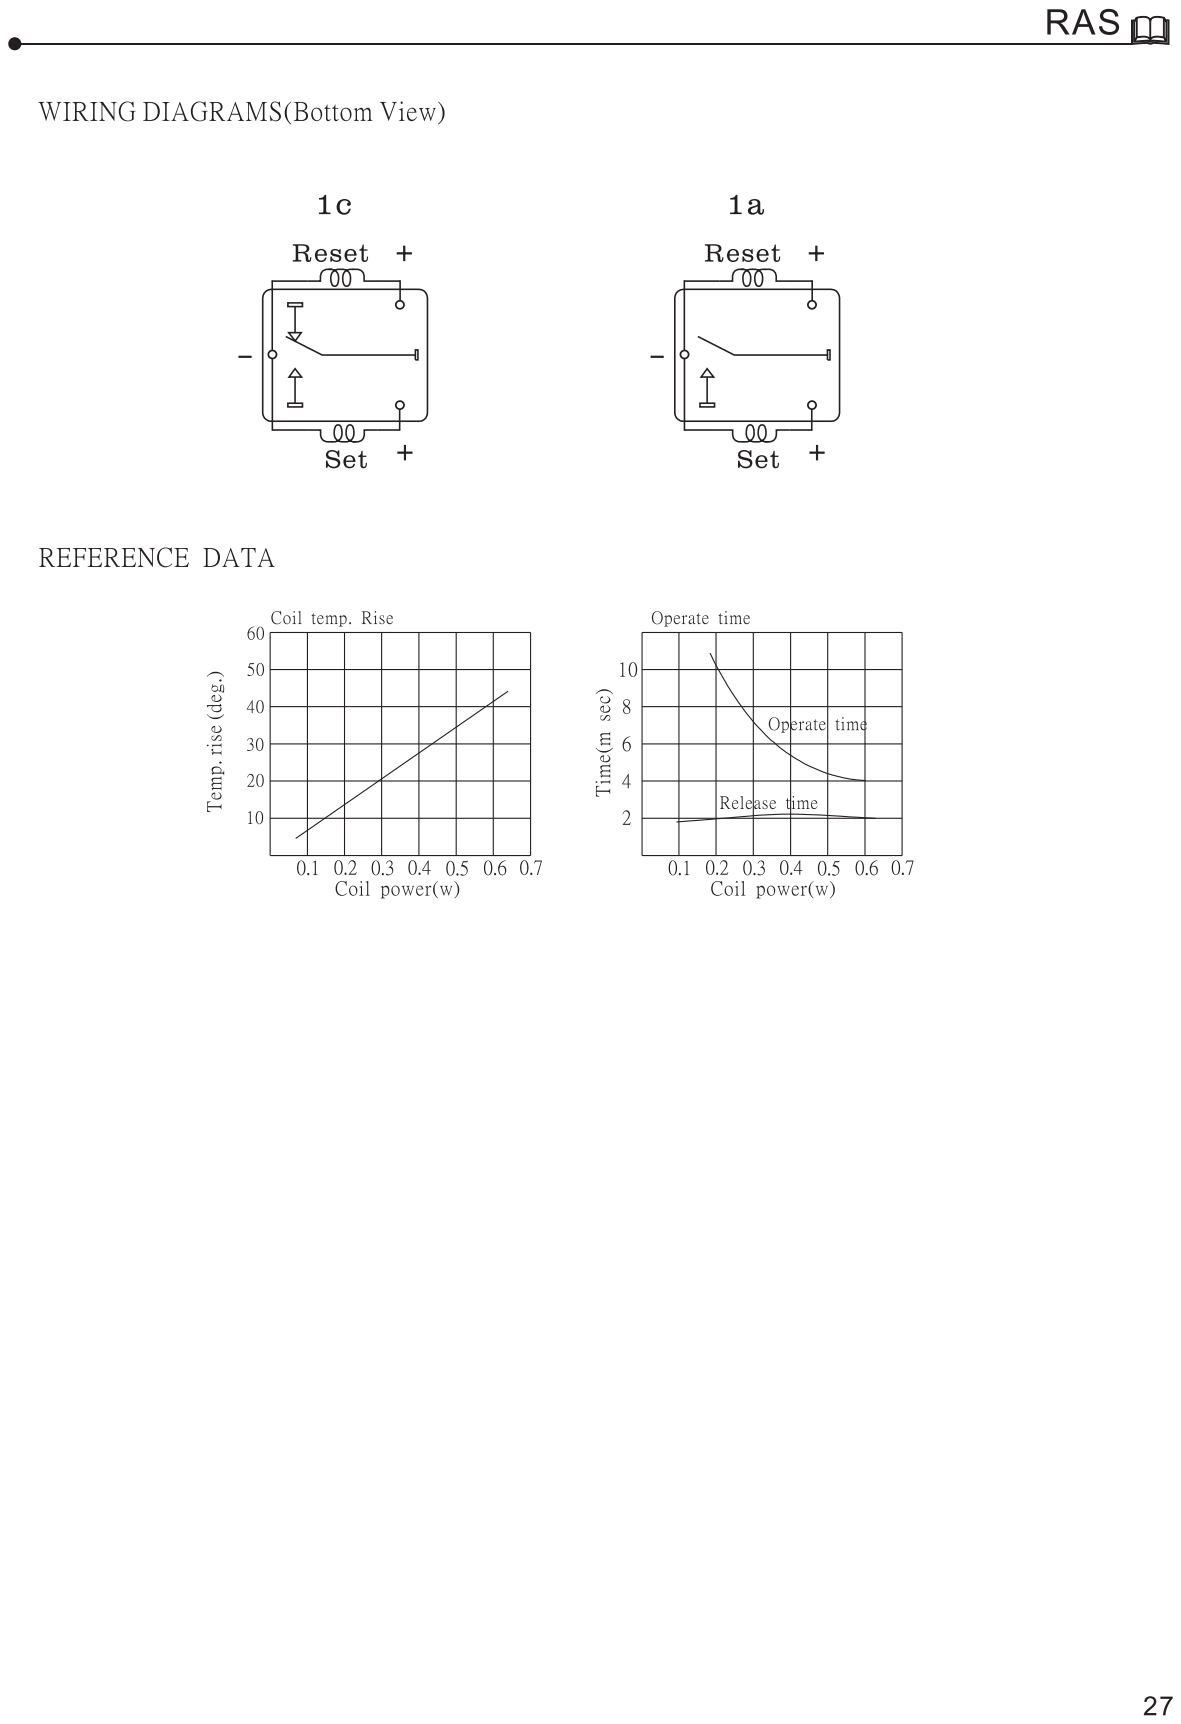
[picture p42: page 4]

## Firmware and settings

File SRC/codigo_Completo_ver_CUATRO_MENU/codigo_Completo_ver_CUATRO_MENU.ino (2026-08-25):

#include <Wire.h>
#include <LiquidCrystal_I2C.h>
#include <Servo.h>
#include "HX711.h"

// ========================================================
// 1. PINES DE LA INTERFAZ (BOTONES Y PANTALLA)
// ========================================================
LiquidCrystal_I2C lcd(0x27, 16, 2); 

const int pinAceptar = 18; 
const int pinArriba = 19;  
const int pinAbajo = 17;   

int cursorMenu = 0;
const int totalOpciones = 7; 
bool actualizarPantalla = true;
volatile bool aceptar = false;
volatile unsigned long ultimoTiempoBoton = 0; 

// ========================================================
// 2. CONFIGURACIÓN DEL MOTOR NEMA
// ========================================================
const int dirPin = 9;    
const int stepPin = 8;  
const int stopPin = 3; 
const int enablePin = 10; 
const int pasoSuave = 3000;

int posicionNema = 0; 

// ========================================================
// 3. CONFIGURACIÓN DE LOS SERVOMOTORES (TAZA Y TOLVAS)
// ========================================================
Servo servoIzq;
Servo servoDer;
const int PIN_SERVO_IZQ = 4;
const int PIN_SERVO_DER = 5;

int anguloPlano = 180;   
int anguloVertido = 50;  
int anguloActual = 180;  
const int VELOCIDAD_MS = 25; 

Servo servoTolva1; 
Servo servoTolva2; 
const int PIN_TOLVA1 = 11;
const int PIN_TOLVA2 = 12;

int tolvaCerrada = 180;  
int tolvaAbierta = 140; 

// --- COMPUERTA UNICEL ---
Servo servoExtra;
const int PIN_SERVO_EXTRA = 13; 
int compuertaExtraCerrada = 0;  
int compuertaExtraAbierta = 90;

// ========================================================
// 4. CONFIGURACIÓN DE LA BÁSCULA Y RELÉS
// ========================================================
#define DT 7
#define SCK 6 
HX711 celda;

float factorEscala = 418.0; 

// --- RELÉS ---
const int pinRele1 = 22; // Bomba de Agua
const int pinRele2 = 23; // Mezcladora


// --- INTERRUPCIÓN DEL BOTÓN "ACEPTAR" ---
void isrBotonAceptar() {
  if (millis() - ultimoTiempoBoton > 500) { 
    aceptar = true;
    ultimoTiempoBoton = millis();
  }
}

// ========================================================
// ESCUDO ANTI-REBOTES (SOLUCIÓN AL SALTO DE MENÚS)
// ========================================================
void esperarLiberacionBoton() {
  // 1. Espera a que quites el dedo físicamente del botón
  while (digitalRead(pinAceptar) == LOW) { 
    delay(10); 
  }
  // 2. Espera a que el metal interno deje de vibrar
  delay(50); 
  
  // 3. ¡LA MAGIA! Reinicia el tiempo para que el ISR no detecte el rebote de soltado
  ultimoTiempoBoton = millis(); 
  aceptar = false; 
}


// --- PASO DEL NEMA ---
void darPaso(int tiempoMicrosegundos) {
  digitalWrite(stepPin, HIGH);
  delayMicroseconds(tiempoMicrosegundos);
  digitalWrite(stepPin, LOW);
  delayMicroseconds(tiempoMicrosegundos);
}

// --- FUNCIÓN DE HOMING ---
void realizarHoming() {
  lcd.clear();
  lcd.setCursor(0, 0);
  lcd.print("Calibrando...");
  lcd.setCursor(0, 1);
  lcd.print("Buscando Cero");

  digitalWrite(enablePin, LOW); 
  delay(10);

  if (digitalRead(stopPin) == LOW) {
    digitalWrite(dirPin, HIGH); 
    while (digitalRead(stopPin) == LOW) { darPaso(pasoSuave); }
    delay(500); 
  }

  digitalWrite(dirPin, LOW); 
  while (digitalRead(stopPin) == HIGH) { 
    darPaso(5000); 
  }
  
  delay(500);
  digitalWrite(dirPin, HIGH); 
  for (int i = 0; i < 20; i++) { darPaso(pasoSuave); }
  
  posicionNema = 0; 
}

// --- MOVIMIENTO DEL NEMA ---
void moverNemaAbsoluto(int posicionDestino) {
  if (posicionDestino == posicionNema) return;

  digitalWrite(enablePin, LOW); 
  delay(10); 

  int pasosAMover = posicionDestino - posicionNema;
  if (pasosAMover > 0) {
    digitalWrite(dirPin, HIGH); 
  } else {
    digitalWrite(dirPin, LOW);  
    pasosAMover = -pasosAMover; 
  }

  for (int i = 0; i < pasosAMover; i++) { darPaso(pasoSuave); }
  posicionNema = posicionDestino; 
}

// --- MOVIMIENTO DE LA TAZA ---
void moverSuaveYDesconectar(int anguloDestino) {
  servoIzq.attach(PIN_SERVO_IZQ, 500, 2500);
  servoDer.attach(PIN_SERVO_DER, 500, 2500);

  int paso = (anguloDestino >= anguloActual) ? 1 : -1;
  for (int a = anguloActual; a != anguloDestino; a += paso) {
    servoIzq.write(a);
    servoDer.write(180 - a);
    delay(VELOCIDAD_MS);
  }
  servoIzq.write(anguloDestino);
  servoDer.write(180 - anguloDestino);
  delay(100);
  servoIzq.detach();
  servoDer.detach();
  anguloActual = anguloDestino;
}

// --- CONTROL DE RECIPIENTES ---
void controlarTolva(int numeroRecipiente, bool abrir) {
  int anguloDestino = abrir ? tolvaAbierta : tolvaCerrada;
  
  if (numeroRecipiente == 1) {
    servoTolva1.attach(PIN_TOLVA1);
    servoTolva1.write(anguloDestino);
    delay(400); 
    servoTolva1.detach(); 
  } 
  else if (numeroRecipiente == 2) {
    servoTolva2.attach(PIN_TOLVA2);
    servoTolva2.write(anguloDestino);
    delay(400); 
    servoTolva2.detach(); 
  }
}

// ========================================================
// MÓDULO DE AUTOMATIZACIÓN Y DOSIFICACIÓN
// ========================================================

void vaciarMaterial() {
  lcd.setCursor(0, 1);
  lcd.print("Vaciando...     "); 
  
  moverSuaveYDesconectar(anguloVertido); 
  delay(1500); 

  servoIzq.attach(PIN_SERVO_IZQ, 500, 2500);
  servoDer.attach(PIN_SERVO_DER, 500, 2500);
  int anguloGolpe = anguloVertido + 20; 

  for (int sacudida = 0; sacudida < 4; sacudida++) {
    servoIzq.write(anguloGolpe);
    servoDer.write(180 - anguloGolpe);
    delay(150); 
    servoIzq.write(anguloVertido);
    servoDer.write(180 - anguloVertido);
    delay(150); 
  }
  servoIzq.detach();
  servoDer.detach();
  
  delay(1500); 
  moverSuaveYDesconectar(anguloPlano); 
}

float esperarLlenado(float pesoObjetivo) {
  float pesoActual = 0.0;

  while (pesoActual < pesoObjetivo) {
    pesoActual = celda.get_units(3); 
    
    lcd.setCursor(0, 1);
    lcd.print("Carga: ");
    lcd.print(pesoActual, 1);
    lcd.print(" g   "); 
    
    delay(10); 
  }
  return pesoActual; 
}

void dosificarPorLotes(int estacionNema, int numeroTolva, float pesoTotalMeta, float capacidadTaza) {
  float pesoAcumulado = 0.0;

  while (pesoAcumulado < pesoTotalMeta) {
    float pesoFaltante = pesoTotalMeta - pesoAcumulado;
    float pesoEsteViaje = (pesoFaltante > capacidadTaza) ? capacidadTaza : pesoFaltante;

    lcd.clear();
    lcd.setCursor(0, 0);
    lcd.print("Mat "); lcd.print(numeroTolva); 
    lcd.print(" "); lcd.print((int)pesoAcumulado); lcd.print("/"); lcd.print((int)pesoTotalMeta); lcd.print("g");

    moverNemaAbsoluto(estacionNema);
    
    lcd.setCursor(0, 1);
    lcd.print("Asentando peso..");
    delay(1500); 
    celda.tare();
    controlarTolva(numeroTolva, true);   
    float servido = esperarLlenado(pesoEsteViaje);      
    controlarTolva(numeroTolva, false);  
    
    pesoAcumulado += servido; 

    realizarHoming(); 
    vaciarMaterial(); 
  }
}

void ejecutarRutinaDosificacion(int multiplicador) {
  digitalWrite(enablePin, LOW); 

  float recetaMaterial1 = 1500.0 * multiplicador;
  float recetaMaterial2 = 1000.0 * multiplicador;

  // ========================================================
  // ¡CORRECCIÓN AQUÍ! Regresamos a las estaciones 50 y 125
  // ========================================================
  dosificarPorLotes(50, 1, recetaMaterial1, 200); 
  dosificarPorLotes(125, 2, recetaMaterial2, 150); 

  lcd.clear();
  lcd.setCursor(0, 0);
  lcd.print("CICLO COMPLETO");
  lcd.setCursor(0, 1);
  lcd.print("Estabilizando..");
  
  delay(1500); 
  digitalWrite(enablePin, HIGH); 
  
  delay(2000); 
  actualizarPantalla = true; 
  aceptar = false; 
}

// ========================================================
// SISTEMA DE CALIBRACIÓN EN VIVO
// ========================================================
void calibrarBascula() {
  lcd.clear();
  lcd.setCursor(0, 0);
  lcd.print("Vacia la taza..");
  delay(2000);
  
  celda.tare(); 
  
  lcd.clear();
  lcd.setCursor(0, 0);
  lcd.print("Pon peso exacto");
  lcd.setCursor(0, 1);
  lcd.print("(Ej. una moneda)");
  delay(3000);

  lcd.clear();
  esperarLiberacionBoton(); // Bloqueo anti-rebote

  while (!aceptar) {
    celda.set_scale(factorEscala);
    float pesoActual = celda.get_units(2);

    lcd.setCursor(0, 0);
    lcd.print("Factor: ");
    lcd.print(factorEscala, 1);
    lcd.print("  "); 
    
    lcd.setCursor(0, 1);
    lcd.print("Peso: ");
    lcd.print(pesoActual, 1);
    lcd.print(" g   ");

    if (digitalRead(pinArriba) == LOW) {
      factorEscala += 1.0; 
      delay(50); 
    }
    if (digitalRead(pinAbajo) == LOW) {
      factorEscala -= 1.0; 
      delay(50);
    }
  }

  lcd.clear();
  lcd.setCursor(0, 0);
  lcd.print("Guardado OK");
  delay(1500);
  
  esperarLiberacionBoton();
  actualizarPantalla = true;
}

// ========================================================
// VISUALIZACIÓN DEL MENÚ
// ========================================================
void mostrarMenu() {
  lcd.clear();
  lcd.setCursor(0, 0);
  lcd.print("MENU PRINCIPAL");
  
  lcd.setCursor(0, 1);
  switch (cursorMenu) {
    case 0: lcd.print("> Agregar Unicel"); break; 
    case 1: lcd.print("> Vertir Material"); break; 
    case 2: lcd.print("> Agregar Agua"); break; 
    case 3: lcd.print("> Mezclar"); break; 
    case 4: lcd.print("> Calibrar Brazo"); break; 
    case 5: lcd.print("> Calibrar Peso"); break; 
    case 6: lcd.print("> Tarar Bascula"); break; 
  }
}

// ========================================================
// SETUP Y LOOP
// ========================================================

void setup() {
  Serial.begin(9600);
  
  pinMode(enablePin, OUTPUT);
  digitalWrite(enablePin, LOW); 

  pinMode(pinArriba, INPUT_PULLUP);
  pinMode(pinAbajo, INPUT_PULLUP);
  pinMode(pinAceptar, INPUT_PULLUP);

  pinMode(pinRele1, OUTPUT);
  digitalWrite(pinRele1, LOW); 
  
  pinMode(pinRele2, OUTPUT);
  digitalWrite(pinRele2, LOW); 
  
  lcd.init();
  lcd.backlight();
  lcd.setCursor(0, 0);
  lcd.print("Iniciando Sist.");

  celda.begin(DT, SCK);
  celda.set_scale(factorEscala); 
  celda.tare();

  servoIzq.write(anguloPlano);
  servoDer.write(180 - anguloPlano);
  servoIzq.attach(PIN_SERVO_IZQ, 500, 2500);
  servoDer.attach(PIN_SERVO_DER, 500, 2500);
  delay(500);
  servoIzq.detach();
  servoDer.detach();

  servoTolva1.write(tolvaCerrada);
  servoTolva2.write(tolvaCerrada);
  servoTolva1.attach(PIN_TOLVA1);
  servoTolva2.attach(PIN_TOLVA2);
  delay(500);
  servoTolva1.detach();
  servoTolva2.detach();

  servoExtra.write(compuertaExtraCerrada);
  servoExtra.attach(PIN_SERVO_EXTRA);
  delay(500);
  servoExtra.detach();

  pinMode(dirPin, OUTPUT);
  pinMode(stepPin, OUTPUT);
  pinMode(stopPin, INPUT_PULLUP);
  
  realizarHoming(); 
  actualizarPantalla = true; 

  delay(1500); 
  digitalWrite(enablePin, HIGH); 

  attachInterrupt(digitalPinToInterrupt(pinAceptar), isrBotonAceptar, FALLING);
}

void loop() {
  
  if (actualizarPantalla) {
    mostrarMenu();
    actualizarPantalla = false;
  }

  if (digitalRead(pinArriba) == LOW) {
    if (cursorMenu > 0) { 
      cursorMenu--; 
      actualizarPantalla = true; 
    }
    delay(200); 
  }

  if (digitalRead(pinAbajo) == LOW) {
    if (cursorMenu < (totalOpciones - 1)) { 
      cursorMenu++; 
      actualizarPantalla = true; 
    }
    delay(200);
  }

  if (aceptar) {
    aceptar = false; 

    switch (cursorMenu) {
      
      // =========================================
      // OPCIÓN 1: AGREGAR UNICEL + HOMING AL FINAL
      // =========================================
      case 0:
        lcd.clear();
        lcd.setCursor(0, 0);
        lcd.print("Moviendo a 125..");
        
        moverNemaAbsoluto(125); 
        
        lcd.clear();
        lcd.setCursor(0, 0);
        lcd.print("Unicel ABIERTO");
        lcd.setCursor(0, 1);
        lcd.print("Pulsa para parar");

        servoExtra.attach(PIN_SERVO_EXTRA);
        servoExtra.write(compuertaExtraAbierta);
        
        esperarLiberacionBoton(); // Bloqueo anti-rebote
        
        while(!aceptar) { 
          delay(10); 
        }
        
        lcd.clear();
        lcd.setCursor(0, 0);
        lcd.print("Cerrando Unicel.");
        servoExtra.write(compuertaExtraCerrada);
        delay(1000);
        servoExtra.detach();

        realizarHoming();
        
        delay(1000);
        digitalWrite(enablePin, HIGH); 
        esperarLiberacionBoton();
        actualizarPantalla = true;
        break;

      // =========================================
      // OPCIÓN 2: VERTIR MATERIAL (CON PORCIONES)
      // =========================================
      case 1:
        { 
          lcd.clear();
          lcd.setCursor(0, 0);
          lcd.print("Porciones:");
          
          esperarLiberacionBoton(); // ¡LA MAGIA AQUÍ! Te permite soltar el botón en paz.
          
          int porcionesElegidas = 1;
          const int maxPorciones = 3; 
          
          while(!aceptar) { 
            lcd.setCursor(0, 1);
            lcd.print("-> ");
            lcd.print(porcionesElegidas);
            lcd.print("             "); 
            
            if (digitalRead(pinArriba) == LOW) {
              if (porcionesElegidas < maxPorciones) {
                porcionesElegidas++;
              }
              delay(200); 
            }
            
            if (digitalRead(pinAbajo) == LOW) {
              if (porcionesElegidas > 1) {
                porcionesElegidas--;
              }
              delay(200);
            }
          }
          
          esperarLiberacionBoton(); // Limpiamos nuevamente antes de arrancar
          ejecutarRutinaDosificacion(porcionesElegidas);
        }
        break;

      // =========================================
      // OPCIÓN 3: AGREGAR AGUA (RELÉ 1)
      // =========================================
      case 2:
        lcd.clear();
        lcd.setCursor(0, 0);
        lcd.print("Control de Agua");
        lcd.setCursor(0, 1);
        lcd.print("Pulsa para ON");
        
        esperarLiberacionBoton(); 
        
        while(!aceptar) { 
          delay(10); 
        }
        
        digitalWrite(pinRele1, HIGH); 
        lcd.setCursor(0, 1);
        lcd.print("Agua: ENCENDIDA ");
        
        esperarLiberacionBoton(); 
        
        while(!aceptar) { 
          delay(10); 
        }
        
        digitalWrite(pinRele1, LOW); 
        lcd.setCursor(0, 1);
        lcd.print("Agua: APAGADA   ");
        
        delay(1500); 
        esperarLiberacionBoton(); 
        actualizarPantalla = true; 
        break;

      // =========================================
      // OPCIÓN 4: MEZCLAR (RELÉ 2)
      // =========================================
      case 3:
        lcd.clear();
        lcd.setCursor(0, 0);
        lcd.print("Control Mezcla");
        lcd.setCursor(0, 1);
        lcd.print("Pulsa para ON");
        
        esperarLiberacionBoton(); 
        
        while(!aceptar) { 
          delay(10); 
        }
        
        digitalWrite(pinRele2, HIGH); 
        lcd.setCursor(0, 1);
        lcd.print("Mezcla: ENCENDIDA");
        
        esperarLiberacionBoton(); 
        
        while(!aceptar) { 
          delay(10); 
        }
        
        digitalWrite(pinRele2, LOW); 
        lcd.setCursor(0, 1);
        lcd.print("Mezcla: APAGADA  ");
        
        delay(1500); 
        esperarLiberacionBoton(); 
        actualizarPantalla = true; 
        break;

      // =========================================
      // OPCIÓN 5: CALIBRAR BRAZO (HOMING)
      // =========================================
      case 4:
        realizarHoming();
        delay(1500);
        digitalWrite(enablePin, HIGH); 
        actualizarPantalla = true;
        break;

      // =========================================
      // OPCIÓN 6: CALIBRAR PESO (FACTOR BÁSCULA)
      // =========================================
      case 5: 
        calibrarBascula();
        break;

      // =========================================
      // OPCIÓN 7: TARAR BÁSCULA (CERO)
      // =========================================
      case 6:
        lcd.clear();
        lcd.setCursor(0, 0);
        lcd.print("Tarando bascula");
        celda.tare();
        delay(1000);
        actualizarPantalla = true;
        break;
    }
  }
}

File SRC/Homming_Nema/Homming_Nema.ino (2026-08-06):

#include <avr/interrupt.h>

const int dirPin = 9;    
const int stepPin = 8;  
const int stopPin = 3; // Limit Switch / Botón en INT1 (Pin 3)

// Flag volatile para detectar cuando la estructura física toca el botón
volatile bool origenEncontrado = false;

// Función dedicada a dar 1 solo paso al motor
void darPaso(int tiempoMicrosegundos) {
  digitalWrite(stepPin, HIGH);
  delayMicroseconds(tiempoMicrosegundos);
  digitalWrite(stepPin, LOW);
  delayMicroseconds(tiempoMicrosegundos);
}

void setup() {
  Serial.begin(9600);

  pinMode(dirPin, OUTPUT);
  pinMode(stepPin, OUTPUT);
  pinMode(stopPin, INPUT_PULLUP); // Pin 3 en HIGH por defecto, pasa a LOW al topar

  // --- CONFIGURACIÓN DE REGISTROS INT1 (Pin 3) ---
  EICRA = 0b00001000;   // Detecta flanco de bajada (FALLING)
  EIFR  |= (1 << INTF1); // Limpia interrupciones fantasmas pendientes
  EIMSK = 0b00000010;   // Habilita interrupción INT1 (Pin 3)

  sei(); // Habilitar interrupciones globales

  Serial.println("Iniciando busqueda de cero (Homing)...");

  // Definimos dirección de búsqueda hacia el botón
  digitalWrite(dirPin, HIGH); 

  // --- FASE 1: BÚSQUEDA A CIEGAS HASTA TOPAR ---
  // El motor gira paso a paso hasta que la interrupción ponga 'origenEncontrado' en true
  while (!origenEncontrado) {
    darPaso(1500); // Gira buscando el tope físico
  }

  // Deshabilitamos la interrupción INT1 para que el botón no interfiera después de calibrar
  EIMSK &= ~(1 << INT1);

  Serial.println("¡Origen (Cero) detectado!");
  Serial.println("Iniciando secuencias en el loop...");
  delay(1000); // Pausa de 1 segundo antes de iniciar el loop
}

void loop() {
  // --- FASE 2: SECUENCIA DE 300 PASOS (1.5 VUELTAS) ---
  
  // 1. Giro a la derecha (300 pasos)
  digitalWrite(dirPin, HIGH);
  Serial.println("Moviendo 300 pasos a la derecha...");
  for (int i = 0; i < 300; i++) {
    darPaso(1500);
  }

  delay(2000); // Pausa de 2 segundos en posición alcanzada

  // 2. Giro a la izquierda de regreso (300 pasos)
  digitalWrite(dirPin, LOW);
  Serial.println("Regresando 300 pasos...");
  for (int i = 0; i < 300; i++) {
    darPaso(1500);
  }

  delay(2000); // Pausa antes de repetir
}

// ISR para la interrupción INT1 (Pin 3)
ISR(INT1_vect) {
  origenEncontrado = true; // Notifica que el botón fue tocado físicamente
}

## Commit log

2026-07-09 Avance Semana 10
    + Imágenes (block de prueba, sistema intregador, material, molde de prueba).
    + Simulación en proteus (modulo relevador).
    + Versión 2.0 del sistema integrador.
    [Eje_Rodillo.SLDPRT, Ensamblaje.SLDASM, Pared_Agujero.SLDPRT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]
2026-07-16 Nuevo código para secuencia de sistema de mesurado
    Se escribió un nuevo código para el sistema integrador el cual tiene más orden, y es más modular para futuras modificaciones de este. Siendo este el código más cercano a la versión final del código a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
2026-07-16 SG90 Datasheet
    Se agregó la hoja de datos de un nuevo material a utilizar, el servomotor SG90. (este se usa para prototipado pero se tiene pensado utilizar otro modelo que tenga más fuerza de torque y soporte carga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
2026-07-16 Reportes semanales 10 y 11
    Se agregaros los reportes semanales de la semana 10 y 11...
2026-07-16 Imágenes (16/7/26)
    se agregaron dos imágenes, una del prototipo del dispensador de material, y otra de cortes de lámina.
2026-08-06 Códigos brazo dosificador
    + Código calibrador de balanza
    + Código de búsqueda de origen para motor a pasos
2026-08-06 Avance semana 12
    Prototipo funcional de brazo dosificador y recipiente dispensador.
2026-08-06 Semana 12
    Diagrama referencia de Homming para motor a pasos (Búsqueda de origen)
2026-08-06 Semana 12
    Se usaron nuevos insumos:
    Arduino MEGA
    Caudalimetro (YF-S201)
    Celda de carga (HX711)
2026-08-06 Semana 12
    + Bomba de agua con caudalimetro
    + Tolva de lámina
2026-08-25 Entrega final
    Imágenes de la estructura, trituradora, mezcladora, depósitos y dosificador
2026-08-25 Código final del sistema dosificador.
    El código agrega la funcionalidad de utilizar por medio de sus controles la mezcladora, el dosificador, la bomba de agua, entre otras funciones:
    -Calibrador de peso del brazo.
    -Calibrador de brazo.
    -Funcionalidad de porciones (una porción equivale un adoquín).
    -Tarar peso del brazo.
2026-08-25 Reporte final
    Reporte final de proyecto intragrador.
2026-08-25 Delete Documentación/Reporte final de proyecto integrador.pdf
    Archivo equivocado
